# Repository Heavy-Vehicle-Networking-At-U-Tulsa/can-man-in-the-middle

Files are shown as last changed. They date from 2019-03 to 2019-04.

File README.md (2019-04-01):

# CAN-man-in-the-middle
or better yet, "can-in-the-middle" is system using the TU Truck Cape, a BeagleBone Black, socketCAN and Python3 to inspect and forward CAN network traffic. Particular interest is on J1939 used in heavy trucks. Contributions to this repository are a result of the funded research on heavy vehicle cybersecurity and digital forensics at the University of Tulsa. 

## Setting up the Hardware
The hardware for this project is 100% open. You can purchase every part of the hardware and hand assemble the pieces. The schematic for the Truck Cape or the CAN Man-in-the-middle is shown in the docs folder. There are multiple hardware versions for different form factors and switching functions. All versions use the BeagleBone Black and have 2 CAN channels and 2 J1708 channels. For more details, see the docs folder.

## Setting up the Operating System (ARM Linux)
The project is based on the following image:

http://debian.beagleboard.org/images/bone-debian-9.5-iot-armhf-2018-10-07-4gb.img.xz

Follow the instructions at http://beagleboard.org/static/beaglebone/latest/README.htm

Here are a couple modifications to the instructions:

We assume you are using Windows 7 or Windows 10:
To install this system on the BeagleBone eMMC do the following: 
  1. Decompress the image using 7-zip: https://www.7-zip.org/download.html
  2. Write the image file to an SD card using Win32 Imager: https://sourceforge.net/projects/win32diskimager/files/latest/download
  3. Insert the micro SD card into the BeagleBone Black.
  3. Boot the system while holding down the SD boot button. A USB cable can power the BBB for this. 
  4. Log into the system by using Putty to ssh into 192.168.7.2 (with USB). The user is `debian` and the password is `temppwd`
  4. At the command prompt, type  `sudo nano /boot/uEnv.txt`. You may have to enter the password again.
  5. Uncomment the last existing line so it says: `cmdline=init=/opt/scripts/tools/eMMC/init-eMMC-flasher-v3.sh` 
  6. reboot: `sudo shutdown -r now`
  7. The system will reboot and after a minuite or so, the LEDs will flash back and forth then light up solid when finished (10 minutes or so).
  8. Remove the SD card and press the reset button or cycle power.
  9. Login again and finish creating the environment.

user: debian

password: temppwd

It may be helpful to connect to the Internet through Ethernet. Once the Ethernet is plugged in, you can check an IP address through the USB connection using `ifconfig`. Look for the IP address for eth0.

BBone Black Wireless has not been tested yet.

## Accessing the BeagleBone Black

### USB
A mini usb connection has an RNDIS connection for treating the connection like a network. The IP address for the USB connection is 192.168.7.2. However, in Windows 10, the driver for this connection is not install correctly by default. To set up the driver for this, please see this guide.

### Ethernet
The BeagleBone Black is setup by default to have a DHCP client to get an IP address. Therefore, a DHCP server is needed for the device to get an IP address.

### Shell Access
SSH is a prefered method to access the operating system. For Windows users, PuTTy is available.

### File Transfer
WinSCP can handle file transfers over a secure connection from a Windows machine.

### Remote Sublime

To edit files using Sublime in on the Beaglebone, there is a package in Sublime Text 3 called RemoteSubl. https://github.com/randy3k/RemoteSubl

http://blog.keyrus.co.uk/editing_files_on_a_remote_server_using_sublime.html

## Creating the environment.

The baseline is the 4.14.71 Linux Kernel. Verify you have the correct operating system installed. Try the following commands and compare the output.

```
debian@beaglebone:~$ uname -a
Linux beaglebone 4.14.71-ti-r80 #1 SMP PREEMPT Fri Oct 5 23:50:11 UTC 2018 armv7l GNU/Linux
```

```
debian@beaglebone:~$ cat /etc/os-release
PRETTY_NAME="Debian GNU/Linux 9 (stretch)"
NAME="Debian GNU/Linux"
VERSION_ID="9"
VERSION="9 (stretch)"
ID=debian
HOME_URL="https://www.debian.org/"
SUPPORT_URL="https://www.debian.org/support"
BUG_REPORT_URL="https://bugs.debian.org/"
```

```
debian@beaglebone:~$ cat /etc/debian_version
9.5
```

```
debian@beaglebone:~$ cat /etc/dogtag
BeagleBoard.org Debian Image 2018-10-07
```

### Controlling Relays
In the hardware revisions with relays (versions 3 and 4), the configuration of the relay switches enables the MITM to be moved between different networks. 

All relays and LEDs require the 5V0 to be present, which comes from the 12V source. This means if the device is powered with just the USB, the relays won't work.

From the command line:

#### Switch 1
`config-pin P8_39 0`  disconnects J1939 from either side (man-in-the-middle mode).

`config-pin P8_39 1`  connects J1939 (Pins C and D) on the A side to J1939 on the B side (passthrough mode).

#### Switch 2
`config-pin P8_40 0`  connects CAN2 (Pins H and J) on the A side to CAN2 on the B side (passthrough mode).

`config-pin P8_40 1`  disconnects CAN2 from either side (man-in-the-middle mode).

#### Switch 3
`config-pin P8_37 0`  connects the `can1` socket to J1939 (Pins C and D) on the A side.

`config-pin P8_37 1`  connects the `can1` socket to CAN2 (Pins H and J) on the A side.

#### Switch 4
`config-pin P8_42 0` connects J1708 (Pins F and G) on the A side to J1708 (Pins F and G) on the B side.

`config-pin P8_42 1` disconnects J1708 from either side (requires software bridge).

#### Switch 5

`config-pin P8_45 0` connects J1939 (Pins C and D) on the B side to `can0`.

`config-pin P8_45 1` connects CAN2 (Pins H and J) on the B side to `can0`.

#### Switch 6

`config-pin P8_46 0` connects terminating resistors.

`config-pin P8_46 1` connects both beaglebone CAN channels together.

#### LED
`config-pin P8_38 0`  Turns off the board mounted LED.

`config-pin P8_38 1`  Turns on the board mounted LED.

#### Using Python
The `os.system` command enables execution of these commands.

```
debian@beaglebone:~$ python3
Python 3.5.3 (default, Jan 19 2017, 14:11:04)
[GCC 6.3.0 20170118] on linux
Type "help", "copyright", "credits" or "license" for more information.
>>> import os
>>> os.system("config_pin P8_38 1")
```

Or, you can use Adafruit's Python Package:

`sudo apt-get install build-essential python-dev python-pip3 -y`

`sudo pip3 install Adafruit_BBIO`

Example of turning on the LED:
```
debian@beaglebone:~$ python3
Python 3.5.3 (default, Sep 27 2018, 17:25:39)
[GCC 6.3.0 20170516] on linux
Type "help", "copyright", "credits" or "license" for more information.
>>> import Adafruit_BBIO.GPIO as GPIO
>>> GPIO.setup("P8_38",GPIO.OUT)
>>> GPIO.output("P8_38",GPIO.HIGH)
```

### Enabling Relays and CAN on Boot

`sudo nano /boot/uEnv.txt`

Change the following block by uncommenting some lines shown below:

```
###Disable auto loading of virtual capes (emmc/video/wireless/adc)
#disable_uboot_overlay_emmc=1
disable_uboot_overlay_video=1
disable_uboot_overlay_audio=1
#disable_uboot_overlay_wireless=1
disable_uboot_overlay_adc=1
```
Exit and save the file.

Restart `sudo shutdown -r now`

We need to load the GPIO settings into the system to use them.

`sudo nano /etc/rc.local`

Copy the rc.local file contents into this editor. The rc.local file runs on boot. It uses the `config-pin` command to set the pins to the appropriate function (like GPIO or CAN)

`sudo chmod 755 rc.local`

Restart the system. `sudo shutdown -r now`.

`sudo sh rc.local` should produce a series of relay clicks and leave the LED on.

#### Python Program to control relays
A Python module is available to setup common relay configurations or control each relay individually. The examples are as follows:

```
debian@beaglebone:~$ python3
Python 3.5.3 (default, Sep 27 2018, 17:25:39)
[GCC 6.3.0 20170516] on linux
Type "help", "copyright", "credits" or "license" for more information.
>>> from mitmRelays import *
>>> mitm = MITM()
>>> mitm.LED(True)
>>> mitm.switch_1(True)
>>> mitm.switch_1(False)
>>> mitm.switch_2(True)
>>> mitm.switch_2(False)
>>> mitm.switch_3(True)
>>> mitm.switch_3(False)
>>> mitm.switch_4(True)
>>> mitm.switch_4(False)
>>> mitm.switch_5(True)
>>> mitm.switch_5(False)
>>> mitm.switch_6(True)
>>> mitm.switch_6(False)
>>> mitm.passthrough_all_monitor_j1939()
>>> mitm.passthrough_all_monitor_can2()
>>> mitm.mitm_can2()
>>> mitm.mitm_J1939() 
```
#### Autostart can0 and can1
To bring up both CAN interfaces at boot change `/etc/network/interfaces` with the following commands

```
sudo nano /etc/network/interfaces
```

Add these lines at the end of the file.
```
allow-hotplug can0
iface can0 can static
    bitrate 250000
    restart-ms 250
 
allow-hotplug can1
iface can1 can static
    bitrate 250000
    restart-ms 250
```

#### Changing CAN bitrates

```
sudo ip link set can1 down
sudo ip link set can1 type can bitrate 500000 restart-ms 200
sudo ip link set can1 up
```

#### Check CAN Statistics
```
ip -details -statistics link show can1
```

### Exceptions for the Forensic Link Adapter
If running on an FLA, turn the dual CAN switch on and make the change available on boot by adding the following script to `/etc/rc.local`

```
sudo nano /etc/rc.local
```
Enter the following lines:
```
#!/bin/sh -e
echo "70" > /sys/class/gpio/export
echo "out" > /sys/class/gpio/gpio70/direction
echo "1" > /sys/class/gpio/gpio70/value
exit 0
```
Save with Control-X, Y, Enter. Then make it executable:
```
sudo chmod 755 /etc/rc.local
sudo shutdown -r now
```

### Python and CAN
Python 3.5 is installed at this version of Linux. To test this
```
debian@beaglebone:~$ python3
Python 3.5.3 (default, Jan 19 2017, 14:11:04)
[GCC 6.3.0 20170118] on linux
Type "help", "copyright", "credits" or "license" for more information.
>>>
```
Python comes with sockets and socketCAN, which is available by default.
You can also install python-can as an interface:
```
python3 -m pip install python-can
```
Building the dependency of `wrapt` failed to build, but the pip command completed.
 
#### Example Program
The following is a basic Python3 program to forward can messages from one socket to another.
```
#!/bin/env python
import socket
import struct

canformat = '<IB3x8s'

class CanBridge():
    def __init__(self, interface_from, interface_to):
        self.interface_from = interface_from
        self.interface_to = interface_to
        self.canSocket_to = socket.socket(socket.PF_CAN, socket.SOCK_RAW, socket.CAN_RAW)
        self.canSocket_from = socket.socket(socket.PF_CAN, socket.SOCK_RAW, socket.CAN_RAW)
        try: 
            self.canSocket_to.bind((self.interface_to,))
            self.canSocket_from.bind((self.interface_from,))
        except OSError: 
            print("Could not bind to interfaces")
        #put the sockets in blocking mode.
        self.canSocket_to.settimeout(None)
        self.canSocket_from.settimeout(None)

    def run(self):
        while True:
            raw_bytes = self.canSocket_from.recv(512)
            try:
                self.canSocket_to.send(raw_bytes)
            except OSError: #Buffer overflow usually from lack of connection.
                pass

            rawID,DLC,candata = struct.unpack(canformat,raw_bytes)
            canID = rawID & 0x1FFFFFFF
            candata_string = " ".join(["{:02X}".format(b) for b in candata])
            print("{:08X} {}".format(canID, candata_string))

if __name__ == '__main__':
    bridge = CanBridge('can1','can0')
    bridge.run()
```
Another simple program using the `python-can` library:
```
#!/bin/env python3
import can

bus = can.interface.Bus(bustype='socketcan', channel='can1', bitrate=250000)
try:
    while True:
        message = bus.recv()
        candata_string = " ".join(["{:02X}".format(b) for b in message.data])
        print("{:08X} {}".format(message.arbitration_id, candata_string))
except KeyboardInterrupt:
    bus.shutdown()
    print("Finished.")
```
There is a noticeable delay when starting this program. The output is as follows when connected to a brake controller and a Smart Sensor Simulator 2:
```
18FEBF0B 00 00 7D 7D 7D 7D FF FF
0CFE6E0B 00 00 00 00 00 00 00 00
0CFE6E0B 00 00 00 00 00 00 00 00
0CFE6E0B 00 00 00 00 00 00 00 00
18FEF10B FF 00 00 FF FF FF FF FF
0CFE6E0B 00 00 00 00 00 00 00 00
18F00131 00 00 00 00 00 00 00 00
18F0010B 00 00 00 00 00 00 00 00
18FEF117 00 00 00 00 00 00 00 00
18FEF128 00 00 00 00 00 00 00 00
18FEF121 00 00 00 00 00 00 00 00
18FEF131 00 00 00 00 00 00 00 00
18E00017 00 00 00 00 00 00 00 00
^CFinished.
```

## Testing with an SSS2
Plug in the CAN-in-the-middle to the Smart Sensor Simulator 2 and turn on the keyswitch of the SSS2 (press the knob for 2 seconds).
Log into the BeagleBone and run `candump any` to see a stream of CAN traffic. Both green and red leds on the SSS2should be on.

Try `cangen can0` to see the green led ficker. Try `cangen can1` to see the red led flicker. 

### Using CAN Utils as a bridge

`candump -s 2 -B can0 can1&`

`candump -s 2 -B can1 can0&`

will bridge the two networks.

To make this into a service that runs on boot add these two lines to the `/etc/rc.local` file. 

can-utils is installed in `/usr/bin`
```
$ which candump
/usr/bin/candump
```

### Remote Access
Interfacing with CAN over Ethernet has been done in this project.

https://github.com/Heavy-Vehicle-Networking-At-U-Tulsa/TruckCapeProjects/tree/master/SocketCAN

In this project, CAN data is efficiently transferred over TCP for remote interaction.

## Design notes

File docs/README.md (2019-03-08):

# Hardware revisions that work with the MITM
There are multiple hardware versions that can work with the man-in-the-middle programming. There are two main differences in the hardware that are delineated by where the network switching takes place. The MITM can be either on the normal CAN bus as a single node or it can be physically separating two different busses. If the MITM is inserted into an existing bus and separates it into two different CAN busses, then the terminating resistors need to be installed. In the first iteration of this, an external hardware box was built to make the connections and add terminating resitors. In subsequent builds, this switching was done using relays. 

## Truck Cape with an External Man-in-the-Middle
The circuit board for a small network splitter is in the folder labeled Hardware Version 2. This includes Altium designer files and a schematic. The connection to this board is done with a DSUB-15 connector. The network switching is done by reqiring the outside connectors.

## MITM v3
This board was designed to be a utility for inserting a man-in-the-middle in any heavy vehicle network using a deutsch 9-pin carrying 2 CAN channels and a J1708 channel. The relays on this board are setup to insert the CAN channels on the BeagleBone Black in either of the can channels from the vehicle. The details for the hardware and the errata are contained in the Hardware Version 3 directory.

## MITM v4
The directory labeled Hardware Version 4 includes the source documents for the MITM v4 that includes the fixes needed to make Rev3 MITM functional. This hardware has not been built yet (as of 4 March 2019).

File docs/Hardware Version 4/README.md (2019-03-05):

# CAN MITM Hardware Rev 4

The Schematics are available as a pdf. Revision 4 is a hardware version that fixes the errata of the version 3 board. 

You can buy version 4 boards from [OSH Park](https://oshpark.com/shared_projects/IROrdsvO)

The bill of materials is the same for revision 3.

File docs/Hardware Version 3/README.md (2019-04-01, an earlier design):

# Truck Cape Revision 3 MITM Hardware
This readme describes how to build the Man-in-the-middle Revison 3.

The circuit was insipired by the Truck Cape, which was inspired by the Truck Duck, which was inspired by the Forensic Link Adapter. 

The Schematic is in PDF format.

## Errata
In hardware version 3 MITM, there are a few issues to address:
  1. The relays need to be mounted on the bottom of the board to get the correct polarity of voltage across the coil. This has been fixed in MITM rev 4.
  2. The pin going to P8_41 needs to be clipped off the header or removed. This is for switch 3. A jumper wire needs to be routed from pin3 of U2 to P8_37, which is GPIO78.
  3. The LED1 net was not connected. Add a jumper wire from P8_38 (GPIO79) to U2 Pin 7. 
  4. Relay K2 crosses CAN2 H and L. This is fixed by scratching out the traces and connecting jumper wires to the correct polarity on CAN2HB and CAN2LB.

### Boot Pin Changes
Clip pin 41 to ensure the BeagleBone Black will boot. A mechanical pencil shows where pin 41 on P8 is that need to be removed. This pin is routed to P8_37 to be used.

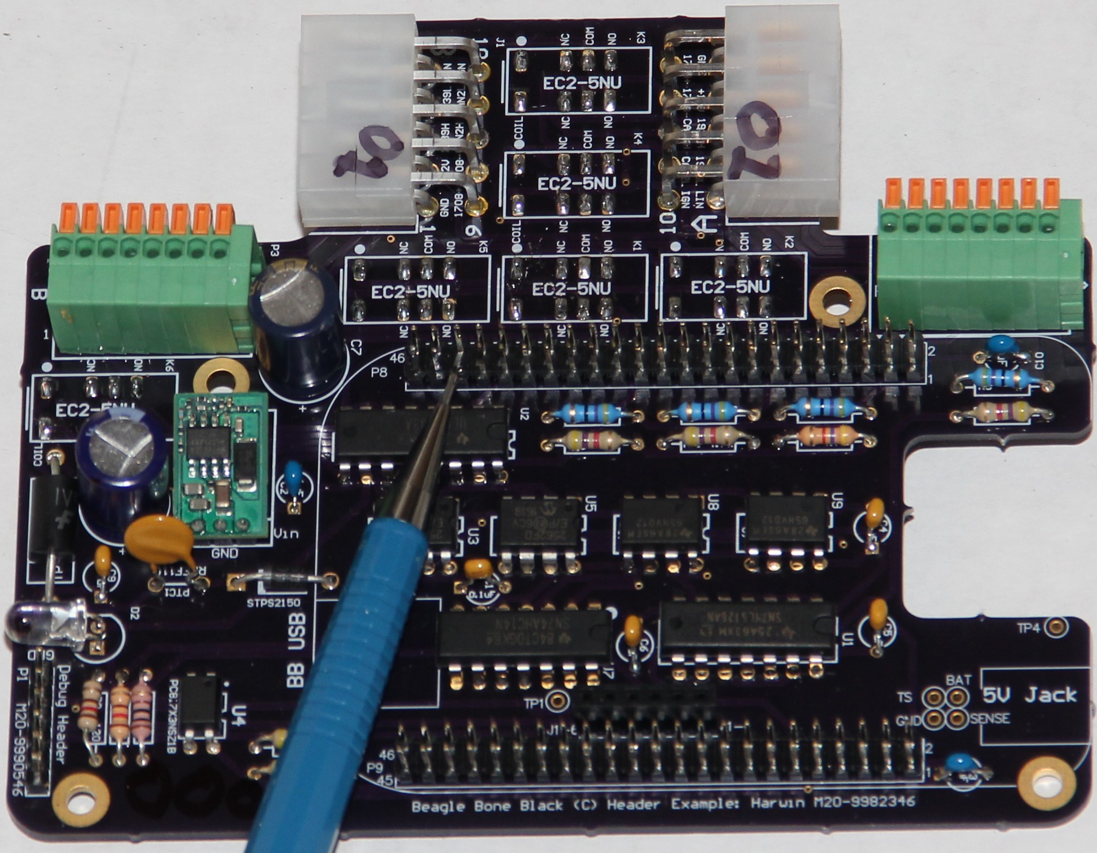
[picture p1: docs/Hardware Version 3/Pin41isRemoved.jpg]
Clip Pin


### Crossed CAN2 Wires
The traces near the relay need to be cut and rerouted. Use a razor knife to cut a small chunk from the two traces for CAN2 between relays K1 and K2 on the top side of the board. See photos.

Cut CAN2H-B

Cut CAN2L-B

Connect the CAN2H wire to the post on K2 that says NC closest to the Beagle Bone and route this to CAN2H on the B side.

Connect the CAN2L wire to the post on K2 directly across from the NC connection and is closest to the Molex Connector and route this to CAN2L on the B side. 

The wires may wrap around the board as seen in the photos.

Topside mount

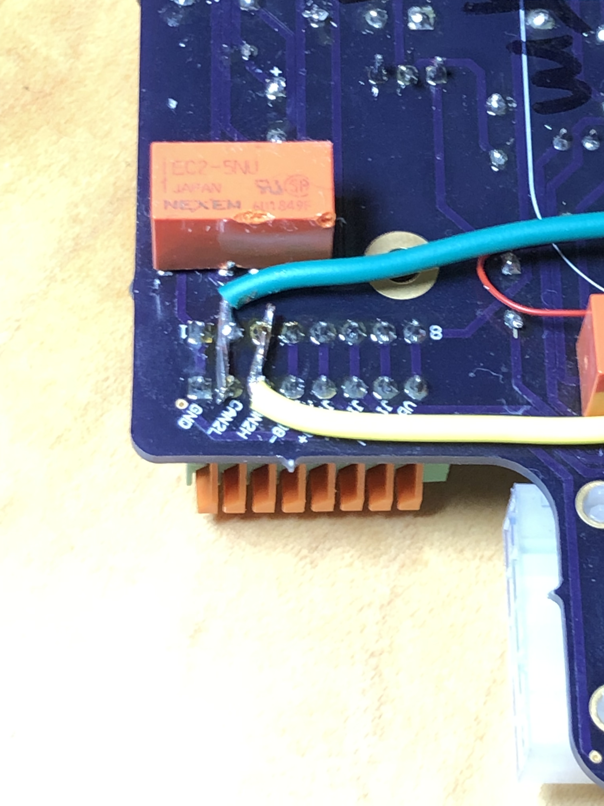
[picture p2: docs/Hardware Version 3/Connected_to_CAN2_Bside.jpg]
Bottomside mount


Bottom View

### Net Labels
The net for Switch4 (P8_42) is connected to Coil4, but that powers Relay K3. This is for the J1708 circuit.

The net for Switch3 (P8_37) is connected to Coil3 powers Relay K4 (after clipping Pin 41). This is for the DCAN1 circuit. This should default to the on position so DCAN1 does not affect CAN2.

## Build process
All parts are through hole parts. A bill of materials in table format is included to help acquire the parts. The silkscreen on the PCB is labeled by part number or value, so hand assembly should be pretty straight forward. Have a look at some of the photos to see the final product.

### Top View

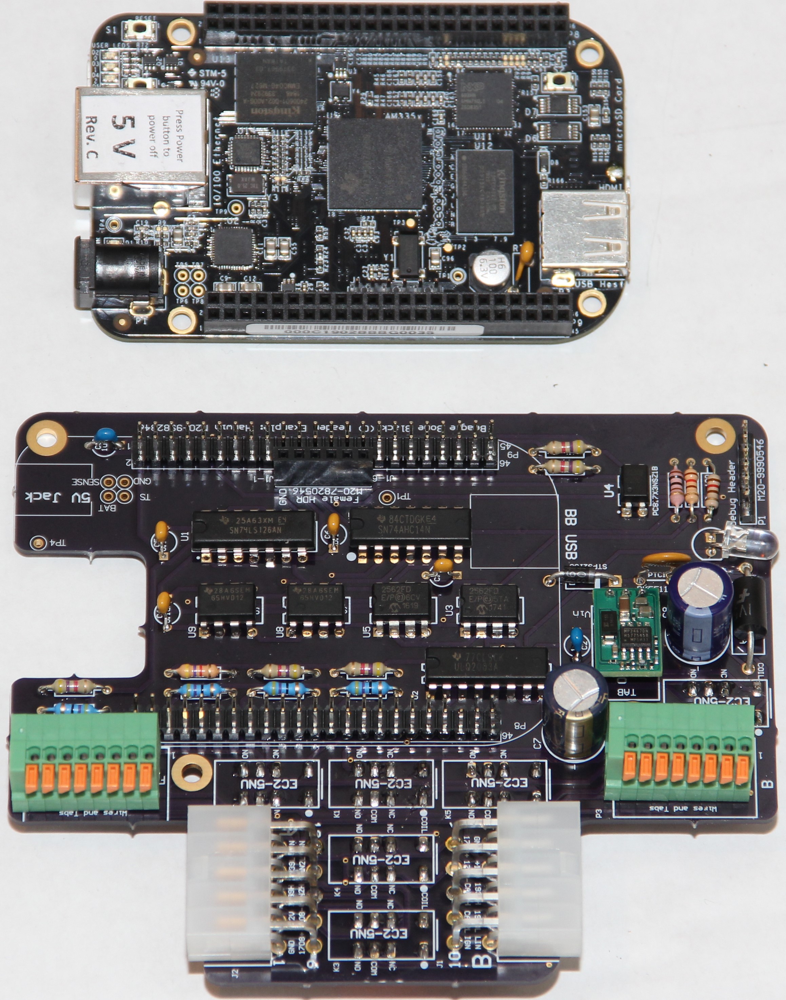
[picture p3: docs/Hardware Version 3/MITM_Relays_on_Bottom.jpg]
Top View


### Bottom View
The bottom of board shows the relays and the wire tracing.

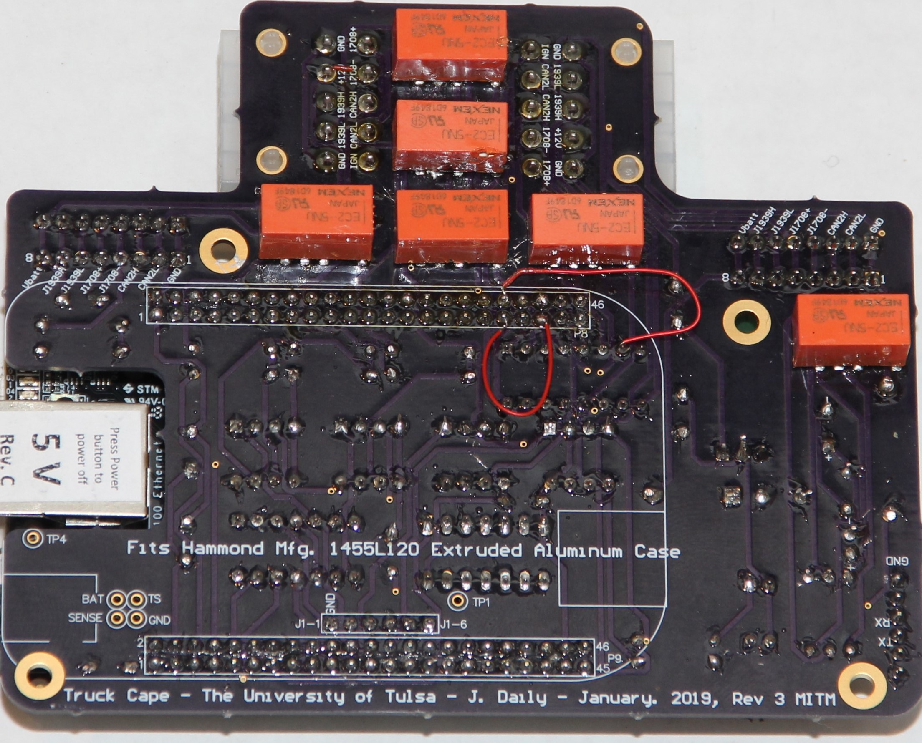
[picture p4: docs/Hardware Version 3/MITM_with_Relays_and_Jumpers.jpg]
Bottom View


The printed circuit board was purchased from OSH Park. Since there are issues with the circuit, this is not a shared board. See the Hardware Revision 4 directory to get a new boards made. 

### End Panels
The end connectors are cut with an epilog laser cutter. Each end is cut one side is for the BeagleBone Black and the other side is for the LED and cables.

The pdf used for the laser cutter has a hole for the cord grip and the BeagleBone Black openings. 

BeagleBone End

LED End

The settings on the 40 watt Epilog laser cutter was 17% speed with 100% power and max frequency. The plastic end panels were placed in the upper left corner of the laser cutter facing down. 

## PCBs
If you want your own boards made, you can send a board house these [gerber files](TruckCapeHammondRev3MITM.zip) as a zip file. However, these boards have the issues corrected by the errata built in; it is advised to use a Rev 4 MITM board.

## Top Level Bill of Materials

| Description | Quantity | Manufacturer | Mfg. Part Number | Supplier Link |
|---|---|---|---|---|
| Anodized extruded aluminum enclosure with plastic end panels | 1 | Hammond Mfg. | 1455N1202BK | [Digi-key](https://www.digikey.com/product-detail/en/hammond-manufacturing/1455N1202BK/HM1501-ND/460176) |
| BeagleBone Black Rev C | 1 | GHI Electropnics LLC | BBB01-SC-505-ND | [Digi-key](https://www.digikey.com/product-detail/en/ghi-electronics-llc/BBB01-SC-505/BBB01-SC-505-ND/6210999) |
| Cord Grip or Cable Gland | 2 | Bud Industries | IPG-22211 | [Digi-key](https://www.digikey.com/product-detail/en/bud-industries/IPG-22211/377-2185-ND/5291487) |
| Cable with Dual Headed 9-pin adapters | 2 | Car-link Auto | KL068-04 | N/A |
| Molex 10 pin Mini-fit Jr connectors | 2 | Molex | 39-01-2100 | [Digi-key](https://www.digikey.com/product-detail/en/molex/39-01-2100/WM3704-ND/61385) |
| Circuit Card Assembly | 1 | DG Technologies | DG-MITM | https://www.dgtech.com |

### Circuit Card Assembly
If you want to build one of these for yourself, the printed circuit board is available as an [order from OSH Park](https://oshpark.com/shared_projects/IROrdsvO).

The bill of materials for the circuit card assembly is as follows:

| Comment |  Designator  | Quantity | Manufacturer | Part Number | Supplier | Supplier Part Number |
| --- | --- | --- | --- | ---  | --- | --- |
| BeagleBoneBlack  | BeagleBoneBlack1 |  2 | Sullins Connector Solutions | PREC023DAAN-RC | Digi-Key | S2012EC-23-ND |
| 0.1uF  | C1, C4, C5, C6, C9  | 5 | Vishay BC Components | K104K20X7RH53H5 | Digi-Key | BC5139-ND |
| 1uF  | C2, C3, C10 | 3 | Murata Electronics North America | RDER72A105K2M1H03A | Digi-Key | 490-9198-1-ND |
| 220uF | C7, C8 |  2 | EPCOS (TDK) | B41858C6227M000 | Digi-Key | 495-6000-ND |
| STPS2150  | D1 | 1 | STMicroelectronics | STPS2150 | Digi-Key | 497-3213-1-ND |
| LED | D2  | 1 | Lite-On Inc. | LTL-4233 | Digi-Key | 160-1130-ND |
| Molex 39-30-1100 | J1, J2  | 2 | Molex | 39-30-1100 | Digi-Key | WM1355-ND |
| EC2-5NU Relay-DPDT  | K1, K2, K3, K4, K5, K6  | 6 | KEMET | EC2-5NU | Digi-Key | 399-11052-5-ND |
| J1-1 to J1-6 |  P1 | 1 | Sullins Connector Solutions | PPPC061LFBN-RC | Digi-Key | S7039-ND |
| Header 8H |  P2, P3 |  2 | Phoenix Contact | 1789472 | Digi-Key | 277-14044-ND |
| RKEF110 | PTC1 | 1 | Littelfuse Inc. | RKEF110 | Digi-Key | RKEF110HF-ND |
| 4.7k | R1, R2, R3, R6, R7, R11, R13  | 7 | Yageo | CFR-25JB-52-4K7 | Digi-Key | 4.7KQBK-ND |
| 47 | R4, R5, R9, R10  | 4 | Yageo | CFR-25JB-52-47R | Digi-Key | 47QBK-ND |
| 120  | R8, R12  | 2 | Yageo | MFP-25BRD52-120R | Digi-Key | 120ADCT-ND |
| SN74LS126AN  | U1  | 1 | Texas Instruments | SN74LS126AN | Digi-Key | 296-3643-5-ND |
| ULQ2003 Darlington Array | U2  | 1 | Texas Instruments | ULQ2003AN | Digi-Key | 296-22623-5-ND |
| MCP2562 | U3, U5 | 2 | Microchip Technology | MCP2562-E/P | Digi-Key | 296-26344-1-ND |
| LTV-817 | U4  | 1 | Lite-On Inc. | LTV-817 | Digi-Key | 160-1366-5-ND |
| OKI-78SR | U6  | 1 | Murata Power Solutions Inc. | OKI-78SR-5/1.5-W36H-C | Digi-Key | 811-2692-ND |
| SN74AHC14N | U7 | 1 | Texas Instruments | SN74AHC14N | Digi-Key | 296-4550-5-ND |
| SN75HVD12  | U8, U9  | 2 | Texas Instruments | SN75HVD12P | Digi-Key | SN75HVD12P |
| TP1.5KE30CA | Z1  | 1 | Littelfuse Inc. | TP1.5KE30CA | Digi-Key | F7610CT-ND |

This bill of materials should match with the schematic labels and the board outlines.

Installing the LED at the end will ensure that it will mate with the hole in the end panel correctly.

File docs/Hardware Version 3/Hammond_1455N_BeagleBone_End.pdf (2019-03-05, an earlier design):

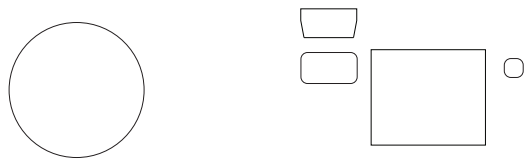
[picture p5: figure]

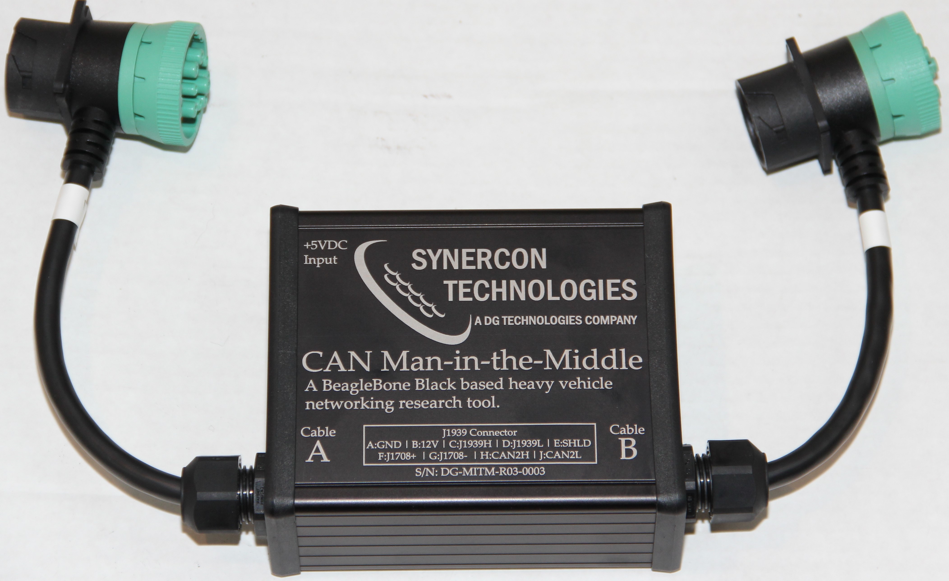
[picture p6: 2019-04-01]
docs/Hardware Version 4/DG Version of CAN Man in the Middle.jpg

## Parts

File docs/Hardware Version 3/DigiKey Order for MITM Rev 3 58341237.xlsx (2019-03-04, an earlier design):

# | Quantity | Part Number | Manufacturer Part Number | Description | Customer Reference | Backorder | Unit Price | Extended Price
1 | 25 | S2012EC-23-ND | PREC023DAAN-RC | CONN HEADER VERT 46POS 2.54MM | P8, P9 | 0 | 0.6576 | 16.44
2 | 100 | BC5139-ND | K104K20X7RH53H5 | CAP CER 0.1UF 100V X7R RADIAL | C1, C4, C5, C6, C9 | 0 | 0.1635 | 16.35
3 | 40 | 490-9198-1-ND | RDER72A105K2M1H03A | CAP CER 1UF 100V X7R RADIAL | C2, C3, C10 | 0 | 0.616 | 24.64
4 | 30 | 495-6000-ND | B41858C6227M000 | CAP ALUM 220UF 20% 50V RADIAL | C7, C8 | 0 | 0.463 | 13.89
5 | 10 | 497-3213-1-ND | STPS2150 | DIODE SCHOTTKY 150V 2A DO15 | D1 | 0 | 0.43 | 4.30
6 | 20 | WM1355-ND | 0039301100 | CONN HEADER R/A 10POS 4.2MM | J1, J2 | 0 | 1.243 | 24.86
7 | 10 | S7039-ND | PPPC061LFBN-RC | CONN HDR 6POS 0.1 GOLD PCB |  | 0 | 0.5 | 5.00
8 | 25 | 732-5319-ND | 61300611121 | CONN HEADER VERT 6POS 2.54MM |  | 0 | 0.232 | 5.80
9 | 65 | 399-11052-5-ND | EC2-5NU | RELAY GEN PURPOSE DPDT 2A 5VDC | K1, K2, K3, K4, K5, K6 | 0 | 1.292 | 83.98
10 | 10 | RKEF110HF-ND | RKEF110 | PTC RESET FUSE 60V 1.1A RADIAL | PTC1 | 0 | 0.519 | 5.19
11 | 100 | 4.7KQBK-ND | CFR-25JB-52-4K7 | RES 4.7K OHM 1/4W 5% AXIAL | R1, R2, R3, R6, R7, R11, R13 | 0 | 0.0258 | 2.58
12 | 50 | 47QBK-ND | CFR-25JB-52-47R | RES 47 OHM 1/4W 5% AXIAL | R4, R5, R9, R10 | 0 | 0.036 | 1.80
13 | 10 | 296-3643-5-ND | SN74LS126AN | IC BUF NON-INVERT 5.25V 14DIP | U1 | 0 | 0.726 | 7.26
14 | 25 | MCP2562-E/P-ND | MCP2562-E/P | IC TXRX CAN 8DIP | U3, U5 | 0 | 0.8036 | 20.09
15 | 10 | 160-1366-5-ND | LTV-817 | OPTOISOLATR 5KV TRANSISTOR 4-DIP | U4 | 0 | 0.294 | 2.94
16 | 10 | 811-2692-ND | OKI-78SR-5/1.5-W36H-C | DC DC CONVERTER 5V 8W | U6 | 0 | 4.474 | 44.74
17 | 10 | 296-4550-5-ND | SN74AHC14N | IC INVERTER SCHMITT 6CH 14DIP | U7 | 0 | 0.476 | 4.76
18 | 20 | 296-14047-5-ND | SN75HVD12P | IC TRANSCEIVER RS485 3.3V 8-DIP | U8, U9 | 0 | 3.675 | 73.50
19 | 10 | F7610CT-ND | TP1.5KE30CA | TVS DIODE 25.6V 41.4V DO201 | Z1 | 0 | 0.757 | 7.57
20 | 10 | 160-1130-ND | LTL-4233 | LED GREEN DIFFUSED T-1 3/4 T/H | D2 | 0 | 0.262 | 2.62
21 | 20 | 277-14044-ND | 1789472 | TERM BLK 8POS TOP ENT 2.54MM PCB | P2, P3 | 0 | 9.325 | 186.50
22 | 10 | 296-22623-5-ND | ULQ2003AN | IC PWR RELAY 7NPN 1:1 16DIP | U2 | 0 | 0.752 | 7.52
23 | 25 | 120ADCT-ND | MFP-25BRD52-120R | RES 120 OHM 1/4W 0.1% AXIAL | R8, R12 | 0 | 0.4068 | 10.17

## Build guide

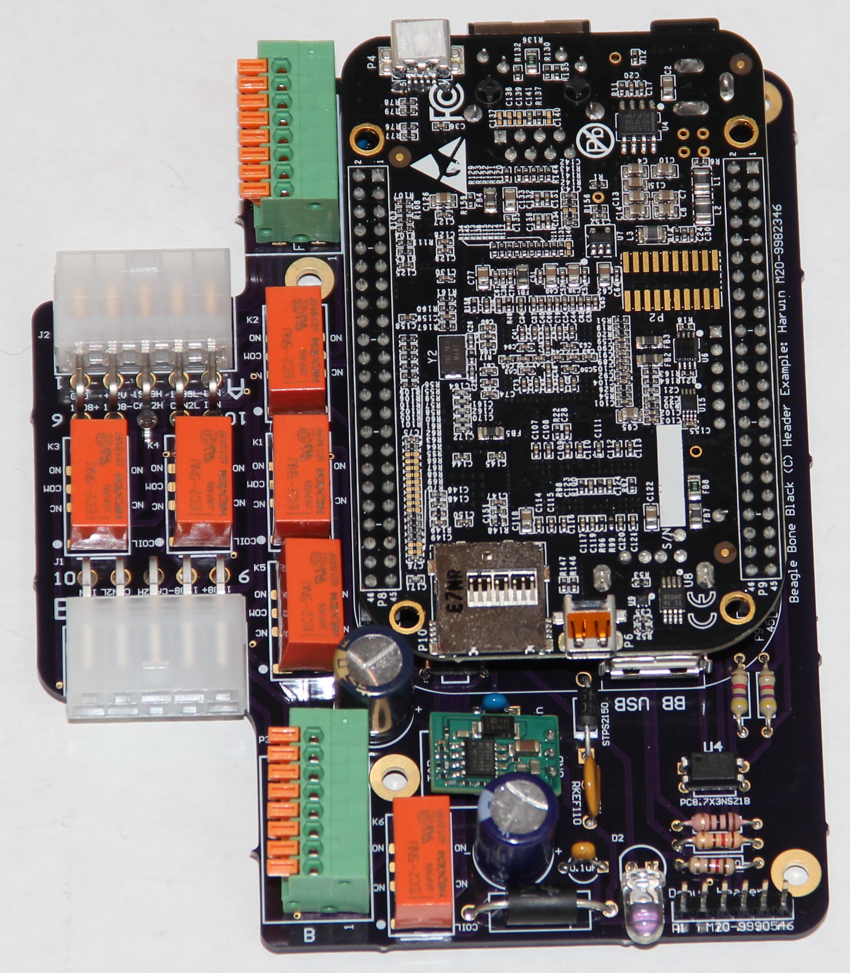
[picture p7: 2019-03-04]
docs/Hardware Version 4/Assembled CAN MITM board top.jpg

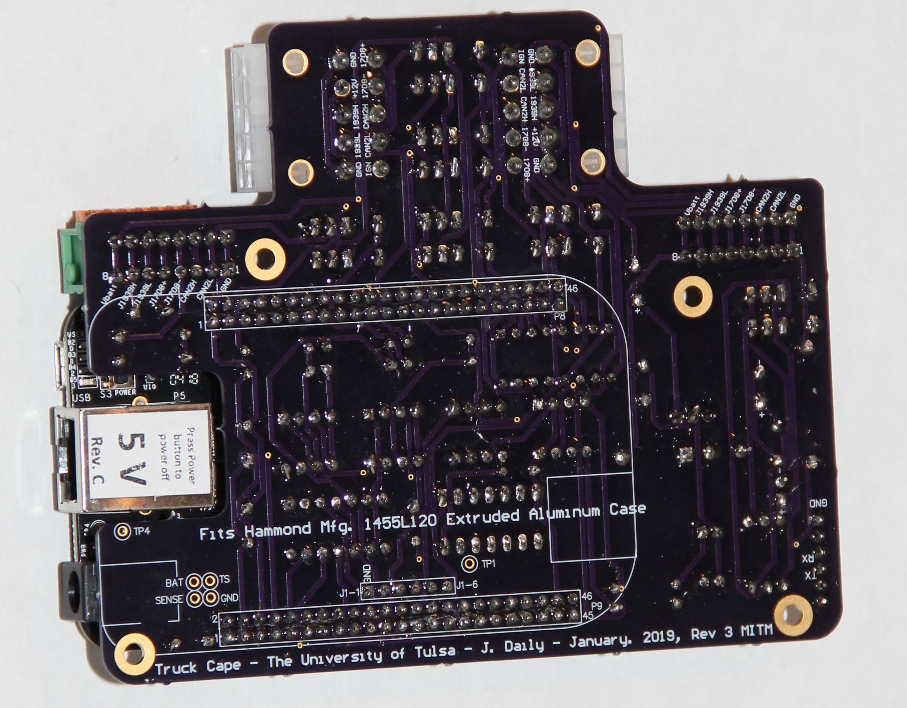
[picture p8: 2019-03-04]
docs/Hardware Version 4/Assembled CAN MITM board bottom.jpg

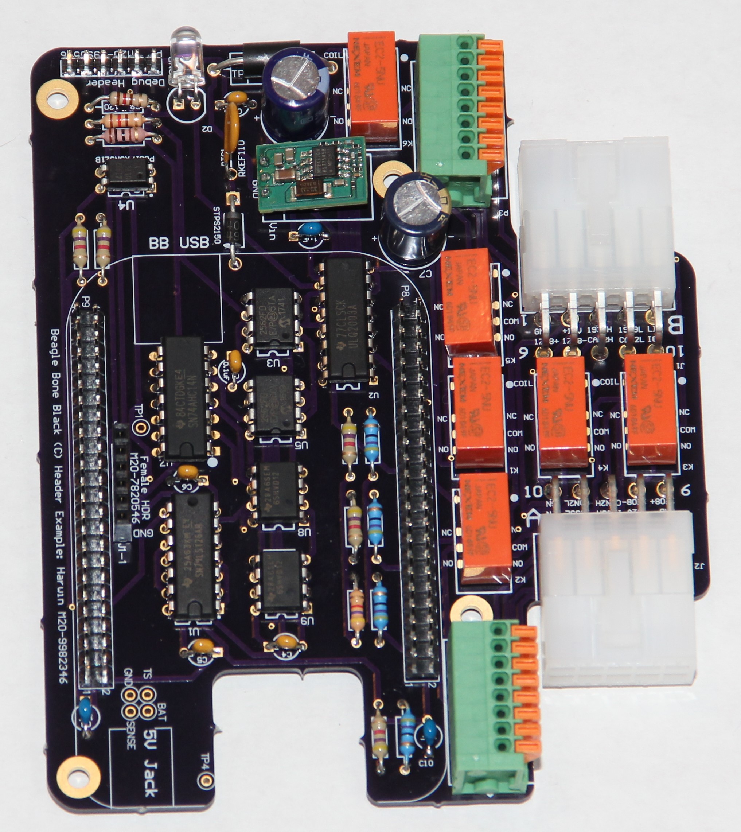
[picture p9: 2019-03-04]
docs/Hardware Version 4/Assembled CAN MITM board top no BBB.jpg

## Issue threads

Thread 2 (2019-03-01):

How to resolve the following error:AttributeError: 'CanBridge' object has no attribute 'run'

Prriyamvradha, 2019-03-01:
I am using two CANtact toolkits(CAN bus) connected by means of DB9 female to DB9 female cable. I want to send CAN a message from one toolkit and the message has to be received in the other toolkit. I used the following code you have mentioned in python3.I get the following error
AttributeError: 'CanBridge' object has no attribute 'run'.How can I resolve it and can this program be used for my case?

```
!/bin/env python
import socket
import struct

canformat = '<IB3x8s'

class CanBridge():
    def __init__(self, interface_from, interface_to):
        self.interface_from = interface_from
        self.interface_to = interface_to
        self.canSocket_to = socket.socket(socket.PF_CAN, socket.SOCK_RAW, socket.CAN_RAW)
        self.canSocket_from = socket.socket(socket.PF_CAN, socket.SOCK_RAW, socket.CAN_RAW)
        try:
            self.canSocket_to.bind((self.interface_to,))
            self.canSocket_from.bind((self.interface_from,))
        except OSError:
            print("Could not bind to interfaces")
        #put the sockets in blocking mode.
        self.canSocket_to.settimeout(None)
        self.canSocket_from.settimeout(None)

    def run(self):
        while True:
            raw_bytes = self.canSocket_from.recv(512)
            try:
                self.canSocket_to.send(raw_bytes)
            except OSError: #Buffer overflow usually from lack of connection.
                pass

            rawID,DLC,candata = struct.unpack(canformat,raw_bytes)
            canID = rawID & 0x1FFFFFFF
            candata_string = " ".join(["{:02X}".format(b) for b in candata])
            print("{:08X} {}".format(canID, candata_string))

if __name__ == '__main__':
    bridge = CanBridge('slcan1','slcan0')
    bridge.run()

```

jeremydaily, 2019-03-01:
This code worked on a BeagleBone Black with a truck cape after I changed  the second to last line to `bridge = CanBridge('can1','can0')`.
The system I tested on was:
```
debian@beaglebone:~$ uname -a
Linux beaglebone 4.14.49-ti-r54 #1 SMP PREEMPT Fri Jun 15 22:14:13 UTC 2018 armv7l GNU/Linux
```
The python version was 3.5. Again, from the terminal:
```
debian@beaglebone:~$ python3
Python 3.5.3 (default, Sep 27 2018, 17:25:39)
[GCC 6.3.0 20170516] on linux
Type "help", "copyright", "credits" or "license" for more information.
>>>
```

Closed 2019-03-01.

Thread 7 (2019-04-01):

Hardware Version 4 schematic still has CAN2-B crossed at K2

traviswparker, 2019-04-01:
The hardware version 4 schematic still has relay K2 connecting CAN2L-A to CAN2H-B and CAN2H-A to CAN2L-B. This is the fault that breaks passthrough on version 3.

jeremydaily, 2019-04-01:
Agreed. There is a hardware version that has been rolled already, so I'll have to post an errata in this directory and look to design a Rev 5 this summer.

Any feature requests?

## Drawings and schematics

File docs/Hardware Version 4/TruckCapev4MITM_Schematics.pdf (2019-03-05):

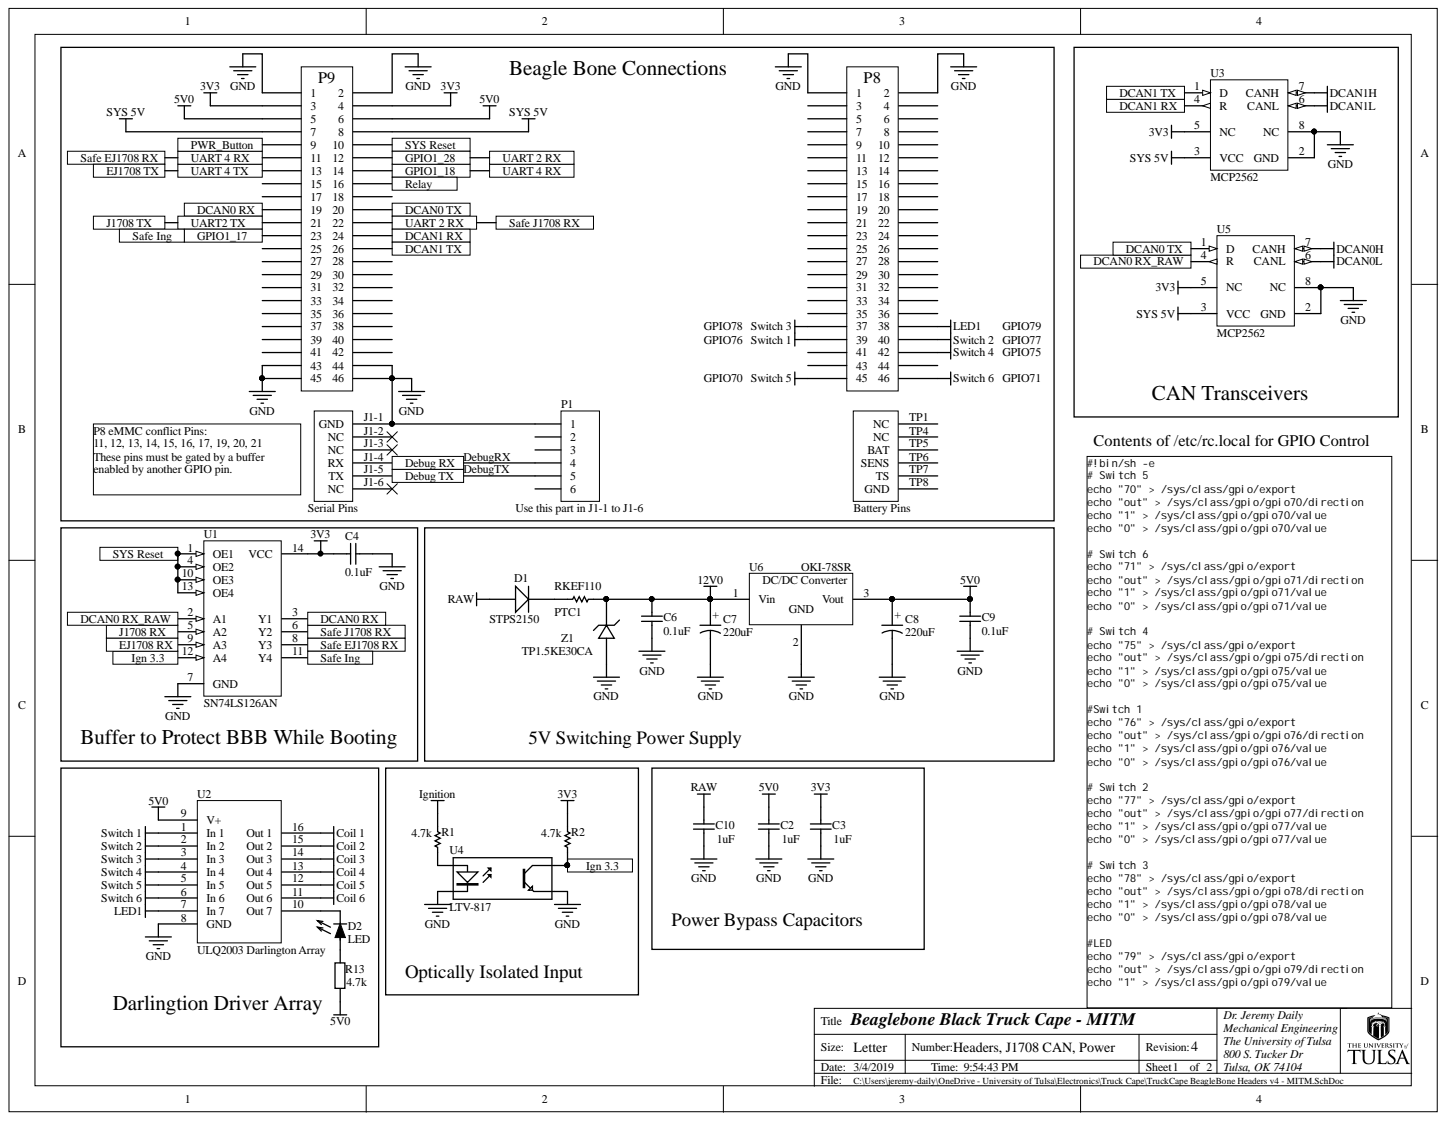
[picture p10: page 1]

P8 eMMC conflict Pins:
These pins must be gated by a buffer
enabled by another GPIO pin.

Contents of /etc/rc.local for GPIO Control

#!bin/sh -e
# Switch 5
echo "70" > /sys/class/gpio/export
echo "out" > /sys/class/gpio/gpio70/direction
echo "1" > /sys/class/gpio/gpio70/value
echo "0" > /sys/class/gpio/gpio70/value

Use this part in J1-1 to J1-6

# Switch 6
echo "71" > /sys/class/gpio/export
echo "out" > /sys/class/gpio/gpio71/direction
echo "1" > /sys/class/gpio/gpio71/value
echo "0" > /sys/class/gpio/gpio71/value

# Switch 4
echo "75" > /sys/class/gpio/export
echo "out" > /sys/class/gpio/gpio75/direction
echo "1" > /sys/class/gpio/gpio75/value
echo "0" > /sys/class/gpio/gpio75/value

EJ1708 RX | Safe EJ1708 RX
Ign 3.3 | Safe Ing

#Switch 1
echo "76" > /sys/class/gpio/export
echo "out" > /sys/class/gpio/gpio76/direction
echo "1" > /sys/class/gpio/gpio76/value
echo "0" > /sys/class/gpio/gpio76/value

Buffer to Protect BBB While Booting

# Switch 2
echo "77" > /sys/class/gpio/export
echo "out" > /sys/class/gpio/gpio77/direction
echo "1" > /sys/class/gpio/gpio77/value
echo "0" > /sys/class/gpio/gpio77/value

# Switch 3
echo "78" > /sys/class/gpio/export
echo "out" > /sys/class/gpio/gpio78/direction
echo "1" > /sys/class/gpio/gpio78/value
echo "0" > /sys/class/gpio/gpio78/value

#LED
echo "79" > /sys/class/gpio/export
echo "out" > /sys/class/gpio/gpio79/direction
echo "1" > /sys/class/gpio/gpio79/value

Beaglebone Black Truck Cape - MITM Title | Dr. Jeremy Daily Mechanical Engineering The University of Tulsa 800 S. Tucker Dr Tulsa, OK 74104

Size: Letter | Headers, J1708 CAN, Power Number: | 4 Revision:

Date: 3/4/2019 | Time: 9:54:43 PM | Sheet 1 of 2

C:\Users\jeremy-daily\OneDrive - University of Tulsa\Electronics\Truck Cape\TruckCape BeagleBone Headers v4 - MITM.SchDoc

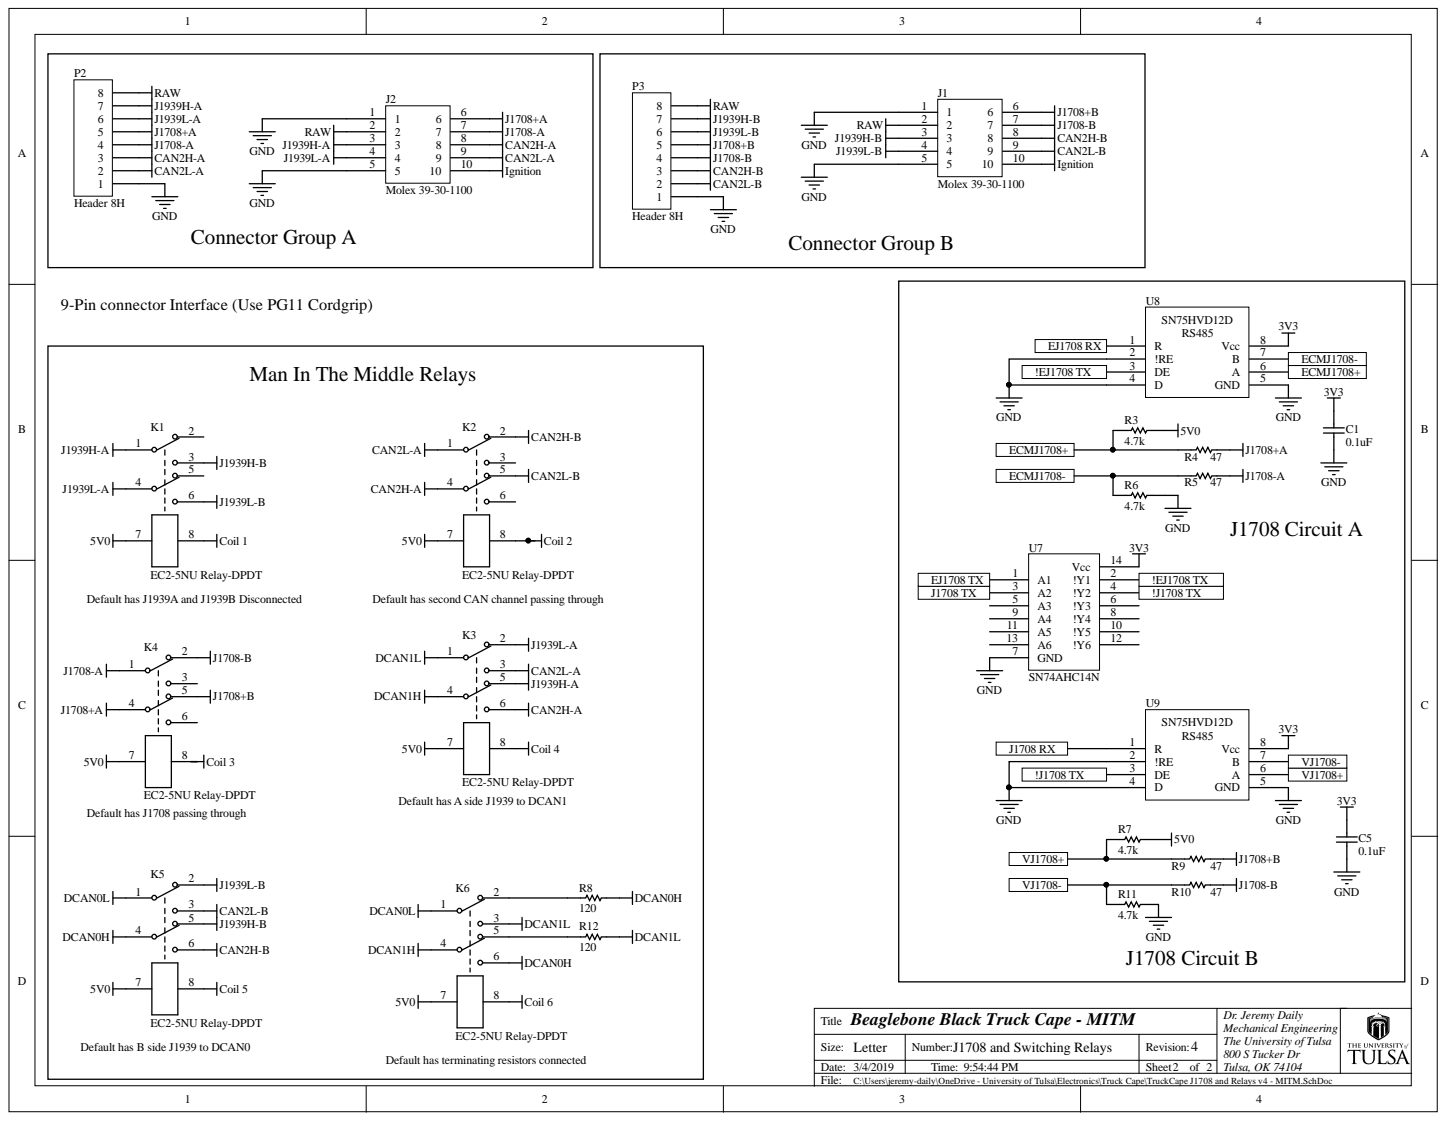
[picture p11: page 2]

9-Pin connector Interface (Use PG11 Cordgrip)

Man In The Middle Relays

!EJ1708 TX | ECMJ1708+

Default has J1939A and J1939B Disconnected

Default has second CAN channel passing through

Default has A side J1939 to DCAN1

Default has J1708 passing through

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

Default has B side J1939 to DCAN0

Size: Letter | J1708 and Switching Relays Number: | 4 Revision:

Default has terminating resistors connected

Date: 3/4/2019 | Time: 9:54:44 PM | Sheet 2 of 2

C:\Users\jeremy-daily\OneDrive - University of Tulsa\Electronics\Truck Cape\TruckCape J1708 and Relays v4 - MITM.SchDoc

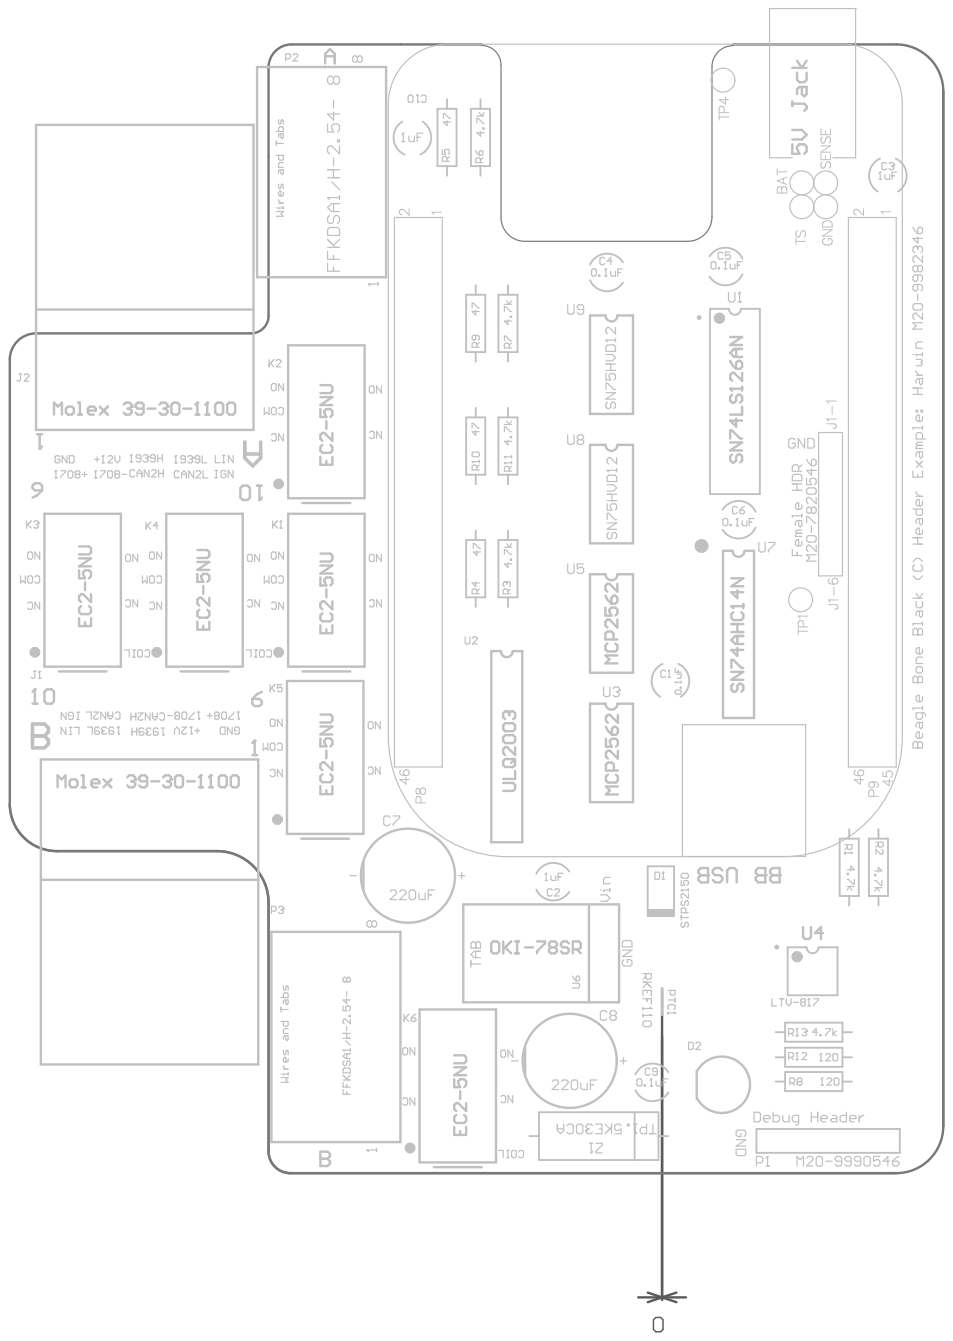
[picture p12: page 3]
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

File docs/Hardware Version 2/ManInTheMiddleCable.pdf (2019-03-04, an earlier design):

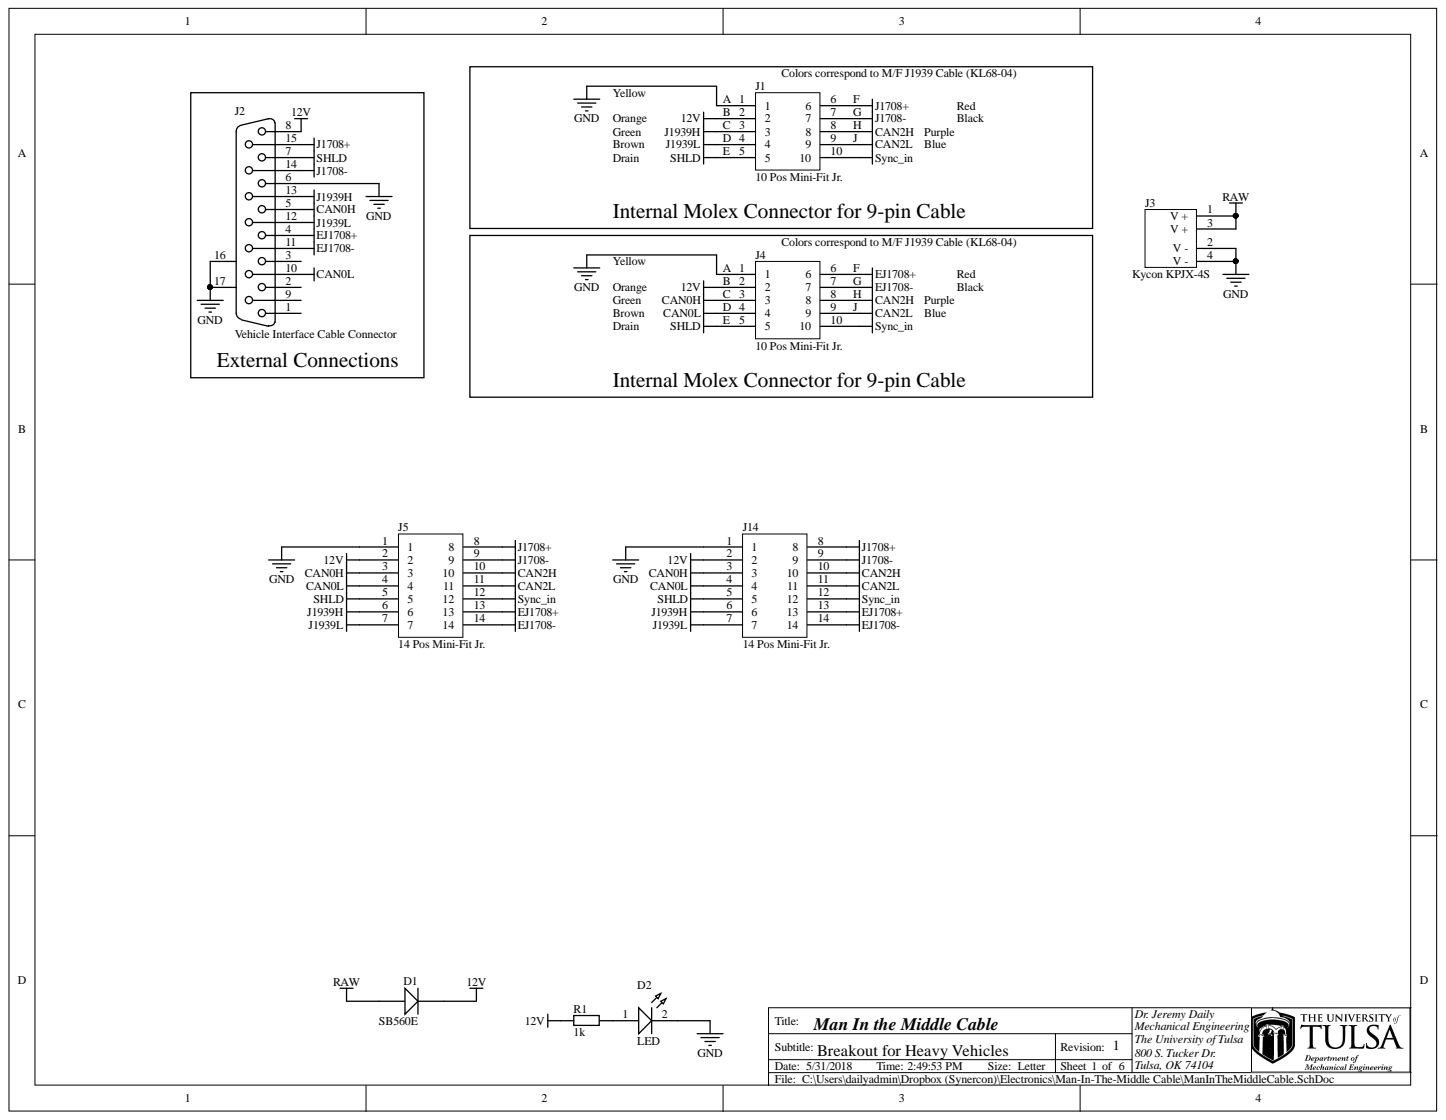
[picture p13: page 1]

Colors correspond to M/F J1939 Cable (KL68-04)

10 Pos Mini-Fit Jr.

Internal Molex Connector for 9-pin Cable

Vehicle Interface Cable Connector
External Connections

14 Pos Mini-Fit Jr.

Title: Man In the Middle Cable | Dr. Jeremy Daily Mechanical Engineering The University of Tulsa 800 S. Tucker Dr. Tulsa, OK 74104

Breakout for Heavy Vehicles Subtitle: | 1 Revision:

Date: 5/31/2018 Time: 2:49:53 PM Size: Letter | Sheet 1 of 6

C:\Users\dailyadmin\Dropbox (Synercon)\Electronics\Man-In-The-Middle Cable\ManInTheMiddleCable.SchDoc

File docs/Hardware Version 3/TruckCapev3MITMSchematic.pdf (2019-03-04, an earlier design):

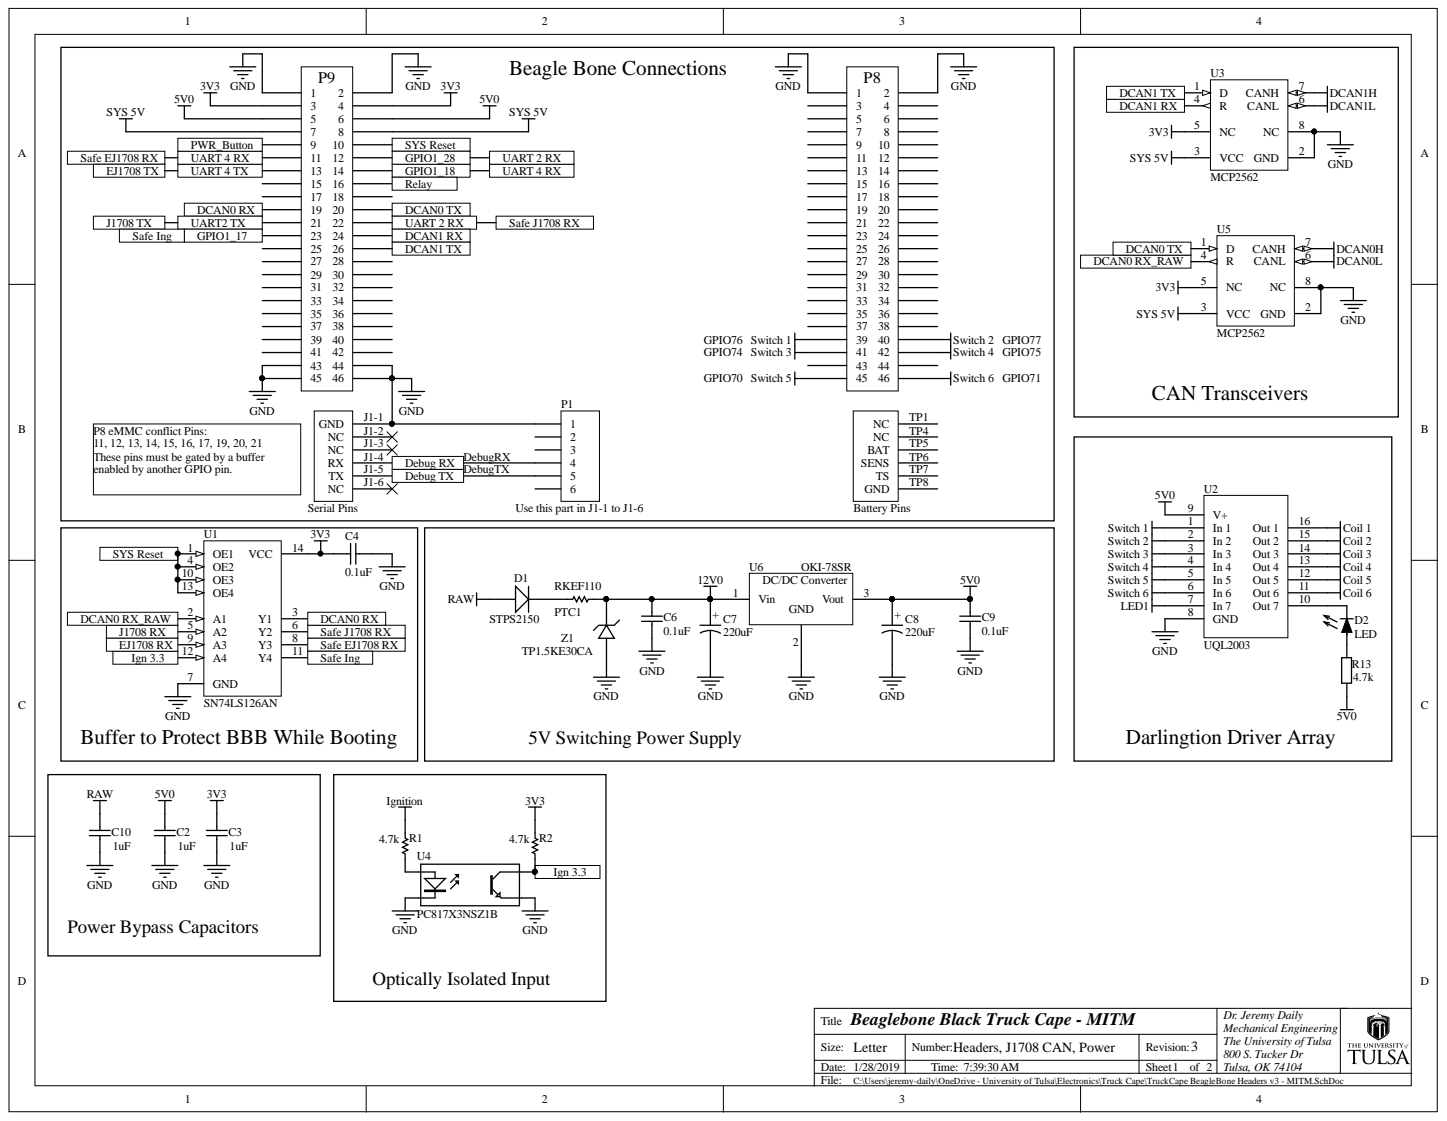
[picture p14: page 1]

P8 eMMC conflict Pins:
These pins must be gated by a buffer
enabled by another GPIO pin.

Use this part in J1-1 to J1-6

Buffer to Protect BBB While Booting

Beaglebone Black Truck Cape - MITM Title | Dr. Jeremy Daily Mechanical Engineering The University of Tulsa 800 S. Tucker Dr Tulsa, OK 74104

Size: Letter | Headers, J1708 CAN, Power Number: | 3 Revision:

Date: 1/28/2019 | Time: 7:39:30 AM | Sheet 1 of 2

C:\Users\jeremy-daily\OneDrive - University of Tulsa\Electronics\Truck Cape\TruckCape BeagleBone Headers v3 - MITM.SchDoc

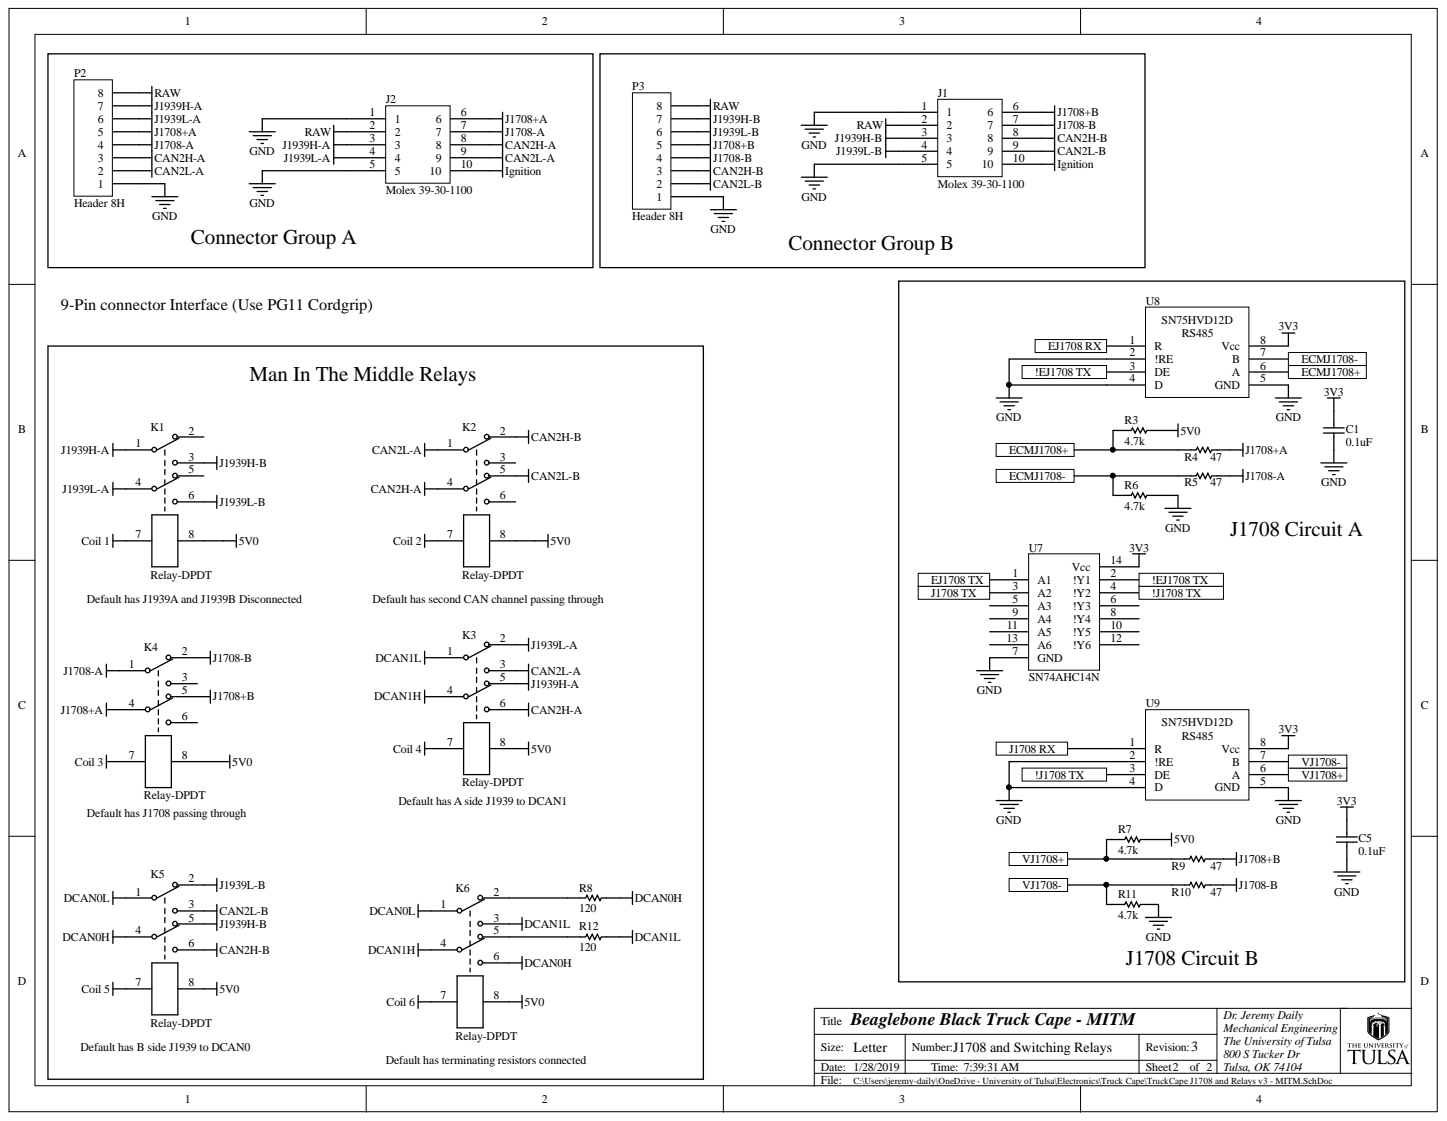
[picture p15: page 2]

9-Pin connector Interface (Use PG11 Cordgrip)

Man In The Middle Relays

!EJ1708 TX | ECMJ1708+

Default has J1939A and J1939B Disconnected

Default has second CAN channel passing through

Default has A side J1939 to DCAN1

Default has J1708 passing through

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

Default has B side J1939 to DCAN0

Size: Letter | J1708 and Switching Relays Number: | 3 Revision:

Default has terminating resistors connected

Date: 1/28/2019 | Time: 7:39:31 AM | Sheet 2 of 2

C:\Users\jeremy-daily\OneDrive - University of Tulsa\Electronics\Truck Cape\TruckCape J1708 and Relays v3 - MITM.SchDoc

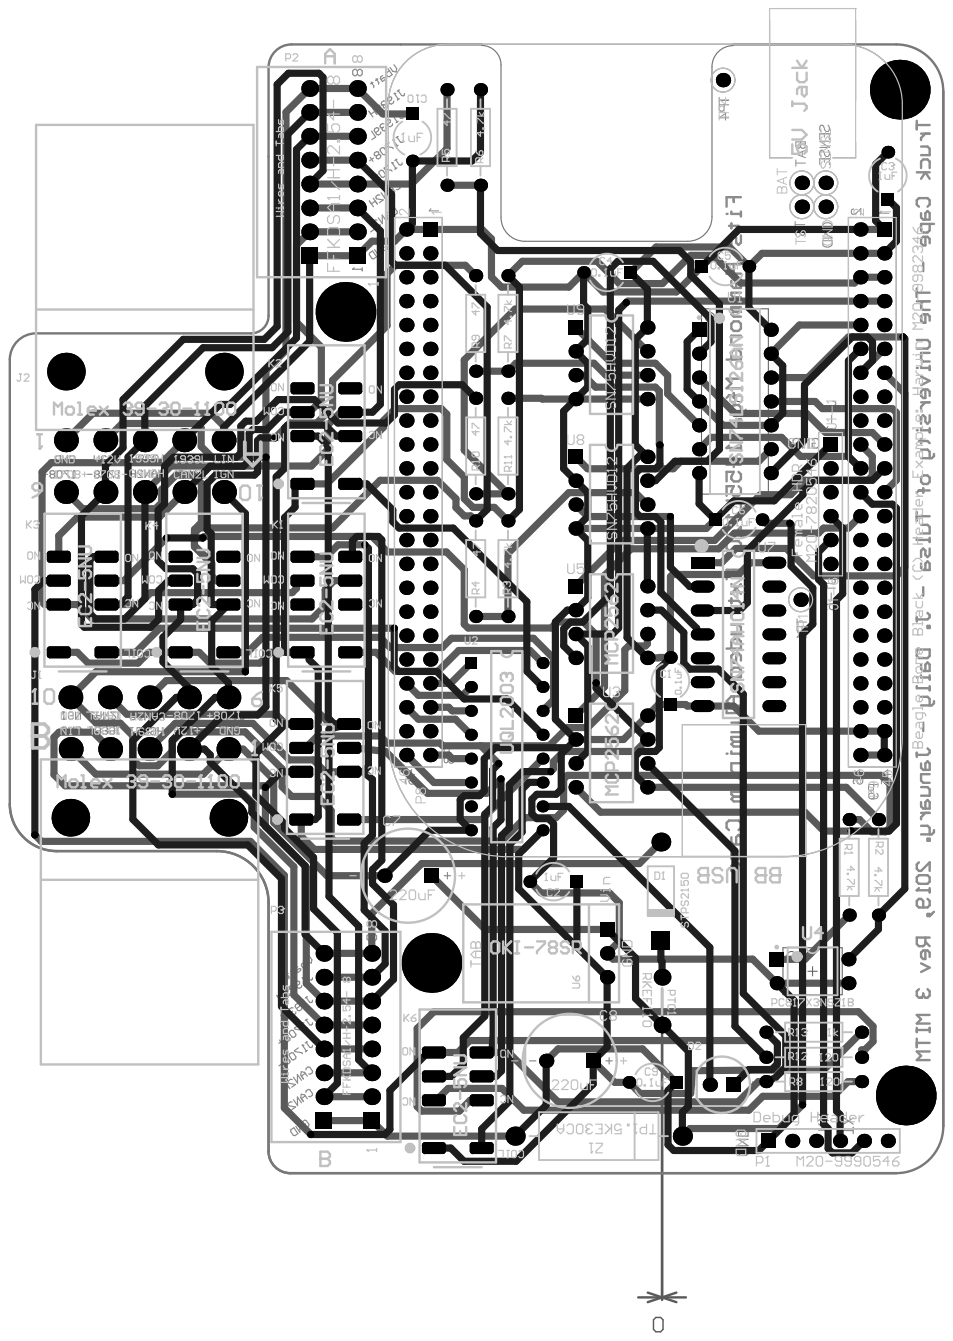
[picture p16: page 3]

Item # | Quantity | Designator | Comment | Footprint | Description | Manufacturer | PartNumber | Supplier 1 | Supplier Part Num#beColr um1 n Name Error:Alte
1 | 1 | BeagleBoneBlack1 | BeagleBoneBlack | Beagleboneblack | 46 Positions Header, Breakaway Connector 0.100" (2.54mm) Through Hole Tin | Sullins Connector Solutions | PREC023DAAN-RC | Digi-Key | S2012EC-23-ND
2 | 5 | C1, C4, C5, C6, C9 | 0.1uF | CAPR5-4X5 | CAP CER 0.1UF 100V X7R RADIAL | Vishay BC Components | K104K20X7RH53H5 | Digi-Key | BC5139-ND
3 | 3 | C2, C3, C10 | 1uF | CAPR5-4X5 | CAP CER 1UF 100V X7R RADIAL | Murata Electronics North America | RDER72A105K2M1H03A | Digi-Key | 490-9198-1-ND
4 | 2 | C7, C8 | 220uF | Elec. Cap 5 x 10mm | 220µF 50V Aluminum Electrolytic Capacitors Radial, Can 175 mOhm @ 10kHz 5000 Hrs @ 105°C | EPCOS (TDK) | B41858C6227M000 | Digi-Key | 495-6000-ND
5 | 1 | D1 | STPS2150 | DO-41 | Diode Schottky 150V 2A Through Hole DO-15 | STMicroelectronics | STPS2150 | Digi-Key | 497-3213-1-ND
6 | 1 | D2 | LED | LED - 5mm Through Hole | Light Emmitting Diode
7 | 2 | J1, J2 | Molex 39-30-1100 | 10 pos Mini-Fit Jr. R/A Header | 10 Positions Header Connector 0.165" (4.20mm) Through Hole, Right Angle Tin | Molex | 39-30-1100 | Digi-Key | WM1355-ND
8 | 6 | K1, K2, K3, K4, K5, K6 | Relay-DPDT | RELAY - EC2 | Dual-Pole Dual-Throw Relay
9 | 1 | P1 | Use this part in J1-1 to J1-6 | HDR1X6 | CONN HEADER FEMALE 6POS .1" GOLD | Sullins Connector Solutions | PPPC061LFBN-RC | Digi-Key | S7039-ND
10 | 2 | P2, P3 | Header 8H | 8 CKT Spring Header | Header, 8-Pin, Right Angle
11 | 1 | PTC1 | RKEF110 | PTC | Polymeric PTC Resettable Fuse 60V 1.1A Ih Through Hole Radial, Disc | Littelfuse Inc. | RKEF110 | Digi-Key | RKEF110HF-ND
12 | 7 | R1, R2, R3, R6, R7, R11, R13 | 4.7k | Axial-0.4 | RES SMD 4.7K OHM 1% 1/10W 0603, Resistor | Yageo, [NoParam] | CFR-25JB-52-4K7, [NoParam] | Digi-Key, [NoParam] | 4.7KQBK-ND, [NoParam]
13 | 4 | R4, R5, R9, R10 | 47 | Axial-0.4 | 47 Ohms ±5% 0.25W, 1/4W Through Hole Resistor Axial Carbon Film | Yageo | CFR-25JB-52-47R | Digi-Key | 47QBK-ND
14 | 2 | R8, R12 | 120 | Axial-0.4 | 47 Ohms ±5% 0.25W, 1/4W Through Hole Resistor Axial Carbon Film | Yageo | CFR-25JB-52-47R | Digi-Key | 47QBK-ND
15 | 1 | U1 | SN74LS126AN | N14A | Quad 3-State Buffer | Texas Instruments | SN74LS126AN | Digi-Key | 296-3643-5-ND
16 | 1 | U2 | UQL2003 | DIP16 | High voltage, high current Darlington arrays each containing seven open collector Darlington pairswith common emitters.
17 | 2 | U3, U5 | MCP2562 | DIP8 | 1/1 Transceiver Half CAN 8-PDIP | Microchip Technology | MCP2562-E/P | Digi-Key | MCP2562-E/P-ND
18 | 1 | U4 | PC817X3NSZ1B | DIP-4 | 4-Pin Phototransistor Optocoupler
19 | 1 | U6 | OKI-78SR | OKI-78SR | 5V DC/DC Converter (7805 replacement) | Murata Power Solutions Inc. | OKI-78SR-5/1.5-W36H-C | Digi-Key | 811-2692-ND
20 | 1 | U7 | SN74AHC14N | DIP14 | Inverter IC 6 Channel Schmitt Trigger 14-PDIP | Texas Instruments | SN74AHC14N | Digi-Key | 296-4550-5-ND
21 | 2 | U8, U9 | SN75HVD12 | DIP8 | IC 3.3V DIFF TXRX 8-SOIC | Texas Instruments | SN75HVD12P | Digi-Key | SN75HVD12P
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

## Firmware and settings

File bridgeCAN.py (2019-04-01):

#!/bin/env python3
import socket
import struct
import os

canformat = '<IB3x8s'

#From https://github.com/torvalds/linux/blob/master/include/uapi/linux/can.h
#special address description flags for the CAN_ID
CAN_EFF_FLAG = 0x80000000 #EFF/SFF is set in the MSB
CAN_RTR_FLAG = 0x40000000 #remote transmission request
CAN_ERR_FLAG = 0x20000000 #error message frame

#valid bits in CAN ID for frame formats
CAN_SFF_MASK = 0x000007FF # /* standard frame format (SFF) */
CAN_EFF_MASK = 0x1FFFFFFF # /* extended frame format (EFF) */
CAN_ERR_MASK = 0x1FFFFFFF # /* omit EFF, RTR, ERR flags */

# 
# Controller Area Network Identifier structure
# 
# bit 0-28 : CAN identifier (11/29 bit)
# bit 29   : error message frame flag (0 = data frame, 1 = error message)
# bit 30   : remote transmission request flag (1 = rtr frame)
# bit 31   : frame format flag (0 = standard 11 bit, 1 = extended 29 bit)
# 

# 
# Controller Area Network Error Message Frame Mask structure
# 
# bit 0-28 : error class mask (see include/linux/can/error.h)
# bit 29-31    : set to zero
# 


# 
# struct can_frame - basic CAN frame structure
# @can_id:  CAN ID of the frame and CAN_*_FLAG flags, see canid_t definition
# @can_dlc: frame payload length in byte (0 .. 8) aka data length code
          # N.B. the DLC field from ISO 11898-1 Chapter 8.4.2.3 has a 1:1
          # mapping of the 'data length code' to the real payload length
# @__pad:   padding
# @__res0:  reserved / padding
# @__res1:  reserved / padding
# @data:    CAN frame payload (up to 8 byte)
# 

# /* particular protocols of the protocol family PF_CAN */
# CAN_RAW     1 /* RAW sockets */
# CAN_BCM     2 /* Broadcast Manager */
# CAN_TP16    3 /* VAG Transport Protocol v1.6 */
# CAN_TP20    4 /* VAG Transport Protocol v2.0 */
# CAN_MCNET   5 /* Bosch MCNet */
# CAN_ISOTP   6 /* ISO 15765-2 Transport Protocol */
# CAN_NPROTO  7


class CanBridge():
    def __init__(self, interface_from, interface_to,bitrate_to=250000,bitrate_from=250000):
        #set CAN bit rates. Must have super user privilages.
        os.system('ip link set {} down'.format(interface_from))
        os.system('ip link set {} type can bitrate {}'.format(interface_from, bitrate_from))
        os.system('ip link set {} up'.format(interface_from))
        os.system('ip link set {} down'.format(interface_to))
        os.system('ip link set {} type can bitrate {}'.format(interface_to, bitrate_to))
        os.system('ip link set {} up'.format(interface_to))

        self.canSocket_to = socket.socket(socket.PF_CAN, 
                                          socket.SOCK_RAW, 
                                          socket.CAN_RAW)
        self.canSocket_from = socket.socket(socket.PF_CAN, 
                                            socket.SOCK_RAW, 
                                            socket.CAN_RAW)
        # Following the RAW Socket Options at
        # https://github.com/torvalds/linux/blob/master/Documentation/networking/can.rst
        # Set receive filters
        # filter passes when <received_can_id> & mask == can_id & mask
        # by setting the mask to zero, all messages pass. 
        can_id = 0
        can_mask = 0
        # Alternatively, to filter out J1939 Cruise Control/Vehicle Speed messages
        # can_id = 0x00FEF100
        # can_mask = 0x00FFFF00 #Just looks at the PGN of 0xFEF1 = 65265
        can_filter = struct.pack('LL',can_id,can_mask)
        
        self.canSocket_to.setsockopt(socket.SOL_CAN_RAW, 
                                     socket.CAN_RAW_FILTER,
                                     can_filter)
        ret_val = self.canSocket_to.getsockopt(socket.SOL_CAN_RAW, socket.CAN_RAW_FILTER)
        print("Socket Option for CAN_RAW_FILTER is set to {}".format(ret_val))
        self.canSocket_from.setsockopt(socket.SOL_CAN_RAW, 
                                     socket.CAN_RAW_FILTER,
                                     can_filter)
        ret_val = self.canSocket_from.getsockopt(socket.SOL_CAN_RAW, socket.CAN_RAW_FILTER)
        print("Socket Option for CAN_RAW_FILTER is set to {}".format(ret_val))
        
        # Set the system to receive every possible error
        can_error_filter = struct.pack('L',CAN_ERR_MASK)
        # Alternatively, we can set specific errors where the errors are enumerated
        # in the defines of /linux/can/error.h
        # can_error_filter = CAN_ERR_TX_TIMEOUT | CAN_ERR_BUSOFF
        self.canSocket_to.setsockopt(socket.SOL_CAN_RAW, 
                                     socket.CAN_RAW_ERR_FILTER,
                                     can_error_filter)
        ret_val = self.canSocket_to.getsockopt(socket.SOL_CAN_RAW, socket.CAN_RAW_ERR_FILTER)
        print("Socket Option for CAN_RAW_ERR_FILTER is set to {}".format(ret_val))
        
        self.canSocket_from.setsockopt(socket.SOL_CAN_RAW, 
                                     socket.CAN_RAW_ERR_FILTER,
                                     can_error_filter)
        ret_val = self.canSocket_from.getsockopt(socket.SOL_CAN_RAW, socket.CAN_RAW_ERR_FILTER)
        print("Socket Option for CAN_RAW_ERR_FILTER is set to {}".format(ret_val))
        
        self.interface_from = interface_from
        self.interface_to = interface_to
        try: 
            self.canSocket_to.bind((interface_to,))
            self.canSocket_from.bind((interface_from,))
        except OSError: 
            print("Could not bind to SocketCAN interfaces")
        #put the sockets in blocking mode.
        self.canSocket_to.settimeout(None)
        self.canSocket_from.settimeout(None)

    def run(self, display=False):
        while True:
            raw_bytes = self.canSocket_from.recv(16)
            try:
                self.canSocket_to.send(raw_bytes)

            except OSError: #Buffer overflow usually from lack of connection.
                if display:
                    print("error writing can.")
                else:
                    pass
            raw_bytes_from = self.canSocket_to.recv(16)
            rawID,DLC,candata = struct.unpack(canformat,raw_bytes_from)
            canID = rawID & 0x1FFFFFFF
            if (rawID & CAN_ERR_FLAG) == CAN_ERR_FLAG:
                print("Found Error Frame.")
                print("RawID: {:08X}, data: {}".format(rawID,candata))

                if canID == 1:
                    print("TX timeout")
                elif canID == 2:
                    print ("Lost arbitration")
                elif canID == 4:
                    print("Controller problems")
                elif canID == 8:
                    print("Protocol violations")
                elif canID == 16:
                    print("Transceiver status") 
                elif canID == 32:
                    print("No Acknkowlegement on transmission")
                elif canID == 64:
                    print("Bus off")
                elif canID == 128:
                    print("{:03X}: Bus error. {}".format(canID,candata))
                elif canID == 0x100:
                    print("Controller restarted")
            elif rawID & CAN_RTR_FLAG == CAN_RTR_FLAG:
                print("Received RTR frame.")
            else:
                #Normal data frame
                if display:   
                    canID = rawID & 0x1FFFFFFF
                    candata_string = " ".join(["{:02X}".format(b) for b in candata])
                    print("{:08X} {}".format(canID, candata_string))

if __name__ == '__main__':
    bridge = CanBridge('can0','can1',bitrate_from=250000,bitrate_to=250000)
    bridge.run()
'''
https://github.com/torvalds/linux/blob/master/include/uapi/linux/can/error.h
/*
 * linux/can/error.h
 *
 * Definitions of the CAN error frame to be filtered and passed to the user.
 *
 * Author: Oliver Hartkopp <oliver.hartkopp@volkswagen.de>
 * Copyright (c) 2002-2007 Volkswagen Group Electronic Research
 * All rights reserved.
 *
 */

#ifndef CAN_ERROR_H
#define CAN_ERROR_H

#define CAN_ERR_DLC 8 /* dlc for error frames */

/* error class (mask) in can_id */
#define CAN_ERR_TX_TIMEOUT   0x00000001U /* TX timeout (by netdevice driver) */
#define CAN_ERR_LOSTARB      0x00000002U /* lost arbitration    / data[0]    */
#define CAN_ERR_CRTL         0x00000004U /* controller problems / data[1]    */
#define CAN_ERR_PROT         0x00000008U /* protocol violations / data[2..3] */
#define CAN_ERR_TRX          0x00000010U /* transceiver status  / data[4]    */
#define CAN_ERR_ACK          0x00000020U /* received no ACK on transmission */
#define CAN_ERR_BUSOFF       0x00000040U /* bus off */
#define CAN_ERR_BUSERROR     0x00000080U /* bus error (may flood!) */
#define CAN_ERR_RESTARTED    0x00000100U /* controller restarted */

/* arbitration lost in bit ... / data[0] */
#define CAN_ERR_LOSTARB_UNSPEC   0x00 /* unspecified */
                      /* else bit number in bitstream */

/* error status of CAN-controller / data[1] */
#define CAN_ERR_CRTL_UNSPEC      0x00 /* unspecified */
#define CAN_ERR_CRTL_RX_OVERFLOW 0x01 /* RX buffer overflow */
#define CAN_ERR_CRTL_TX_OVERFLOW 0x02 /* TX buffer overflow */
#define CAN_ERR_CRTL_RX_WARNING  0x04 /* reached warning level for RX errors */
#define CAN_ERR_CRTL_TX_WARNING  0x08 /* reached warning level for TX errors */
#define CAN_ERR_CRTL_RX_PASSIVE  0x10 /* reached error passive status RX */
#define CAN_ERR_CRTL_TX_PASSIVE  0x20 /* reached error passive status TX */
                      /* (at least one error counter exceeds */
                      /* the protocol-defined level of 127)  */

/* error in CAN protocol (type) / data[2] */
#define CAN_ERR_PROT_UNSPEC      0x00 /* unspecified */
#define CAN_ERR_PROT_BIT         0x01 /* single bit error */
#define CAN_ERR_PROT_FORM        0x02 /* frame format error */
#define CAN_ERR_PROT_STUFF       0x04 /* bit stuffing error */
#define CAN_ERR_PROT_BIT0        0x08 /* unable to send dominant bit */
#define CAN_ERR_PROT_BIT1        0x10 /* unable to send recessive bit */
#define CAN_ERR_PROT_OVERLOAD    0x20 /* bus overload */
#define CAN_ERR_PROT_ACTIVE      0x40 /* active error announcement */
#define CAN_ERR_PROT_TX          0x80 /* error occurred on transmission */

/* error in CAN protocol (location) / data[3] */
#define CAN_ERR_PROT_LOC_UNSPEC  0x00 /* unspecified */
#define CAN_ERR_PROT_LOC_SOF     0x03 /* start of frame */
#define CAN_ERR_PROT_LOC_ID28_21 0x02 /* ID bits 28 - 21 (SFF: 10 - 3) */
#define CAN_ERR_PROT_LOC_ID20_18 0x06 /* ID bits 20 - 18 (SFF: 2 - 0 )*/
#define CAN_ERR_PROT_LOC_SRTR    0x04 /* substitute RTR (SFF: RTR) */
#define CAN_ERR_PROT_LOC_IDE     0x05 /* identifier extension */
#define CAN_ERR_PROT_LOC_ID17_13 0x07 /* ID bits 17-13 */
#define CAN_ERR_PROT_LOC_ID12_05 0x0F /* ID bits 12-5 */
#define CAN_ERR_PROT_LOC_ID04_00 0x0E /* ID bits 4-0 */
#define CAN_ERR_PROT_LOC_RTR     0x0C /* RTR */
#define CAN_ERR_PROT_LOC_RES1    0x0D /* reserved bit 1 */
#define CAN_ERR_PROT_LOC_RES0    0x09 /* reserved bit 0 */
#define CAN_ERR_PROT_LOC_DLC     0x0B /* data length code */
#define CAN_ERR_PROT_LOC_DATA    0x0A /* data section */
#define CAN_ERR_PROT_LOC_CRC_SEQ 0x08 /* CRC sequence */
#define CAN_ERR_PROT_LOC_CRC_DEL 0x18 /* CRC delimiter */
#define CAN_ERR_PROT_LOC_ACK     0x19 /* ACK slot */
#define CAN_ERR_PROT_LOC_ACK_DEL 0x1B /* ACK delimiter */
#define CAN_ERR_PROT_LOC_EOF     0x1A /* end of frame */
#define CAN_ERR_PROT_LOC_INTERM  0x12 /* intermission */

/* error status of CAN-transceiver / data[4] */
/*                                             CANH CANL */
#define CAN_ERR_TRX_UNSPEC             0x00 /* 0000 0000 */
#define CAN_ERR_TRX_CANH_NO_WIRE       0x04 /* 0000 0100 */
#define CAN_ERR_TRX_CANH_SHORT_TO_BAT  0x05 /* 0000 0101 */
#define CAN_ERR_TRX_CANH_SHORT_TO_VCC  0x06 /* 0000 0110 */
#define CAN_ERR_TRX_CANH_SHORT_TO_GND  0x07 /* 0000 0111 */
#define CAN_ERR_TRX_CANL_NO_WIRE       0x40 /* 0100 0000 */
#define CAN_ERR_TRX_CANL_SHORT_TO_BAT  0x50 /* 0101 0000 */
#define CAN_ERR_TRX_CANL_SHORT_TO_VCC  0x60 /* 0110 0000 */
#define CAN_ERR_TRX_CANL_SHORT_TO_GND  0x70 /* 0111 0000 */
#define CAN_ERR_TRX_CANL_SHORT_TO_CANH 0x80 /* 1000 0000 */

/* controller specific additional information / data[5..7] */

#endif /* CAN_ERROR_H */
'''

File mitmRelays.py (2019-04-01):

import Adafruit_BBIO.GPIO as GPIO

class MITM():
    def __init__(self):
        GPIO.setup("P8_38",GPIO.OUT)
        GPIO.setup("P8_39",GPIO.OUT)
        GPIO.setup("P8_40",GPIO.OUT)
        GPIO.setup("P8_37",GPIO.OUT)
        GPIO.setup("P8_45",GPIO.OUT)
        GPIO.setup("P8_42",GPIO.OUT)
        GPIO.setup("P8_46",GPIO.OUT)
    
    def LED(self,state):
        if state:
            GPIO.output("P8_38",GPIO.HIGH)
        else:
            GPIO.output("P8_38",GPIO.LOW)
    
    def switch_1(self,state):
        if state:
            GPIO.output("P8_39",GPIO.HIGH)
        else:
            GPIO.output("P8_39",GPIO.LOW)
    
    def switch_2(self,state):
        if state:
            GPIO.output("P8_40",GPIO.HIGH)
        else:
            GPIO.output("P8_40",GPIO.LOW)
    
    def switch_3(self,state):
        if state:
            GPIO.output("P8_37",GPIO.HIGH)
        else:
            GPIO.output("P8_37",GPIO.LOW)
    
    def switch_4(self,state):
        if state:
            GPIO.output("P8_42",GPIO.HIGH)
        else:
            GPIO.output("P8_42",GPIO.LOW)
    
    def switch_5(self,state):
        if state:
            GPIO.output("P8_45",GPIO.HIGH)
        else:
            GPIO.output("P8_45",GPIO.LOW)
    
    def switch_6(self,state):
        if state:
            GPIO.output("P8_46",GPIO.HIGH)
        else:
            GPIO.output("P8_46",GPIO.LOW)

    def passthrough_all_with_resistors(self):
        """
        Terminating resistors are introduced.
        """
        self.switch_1(True) #Connect J1939
        self.switch_2(False) #Connect CAN2
        self.switch_3(False) #DCAN1 reads J1939
        self.switch_4(False) #Connect J1708
        self.switch_5(True) #DCAN0 reads CAN2
        self.switch_6(False) #Terminating Resitors connected

    def passthrough_all_monitor_j1939(self):
        """
        No Terminating resistors are introduced.
        """
        self.switch_1(False) #Disconnect J1939
        self.switch_2(False) #Connect CAN2
        self.switch_3(False) #DCAN1 reads J1939
        self.switch_4(False) #Connect J1708
        self.switch_5(False) #DCAN0 reads J1939
        self.switch_6(True) #DCAN0 connects to DCAN1
    
    def passthrough_all_monitor_can2(self):
        """
        No Terminating resistors are introduced.
        """
        self.switch_1(True) #connect J1939
        self.switch_2(True) #disconnect CAN2
        self.switch_3(True) #DCAN1 reads CAN2
        self.switch_4(False) #Connect J1708
        self.switch_5(True) #DCAN0 reads CAN2
        self.switch_6(True) #DCAN0 connects to DCAN1

    def mitm_can2(self):
        """
        Terminating resistors are introduced.
        """
        self.switch_1(True) #connect J1939
        self.switch_2(True) #disconnect CAN2
        self.switch_3(True) #DCAN1 reads CAN2A
        self.switch_4(False) #Connect J1708
        self.switch_5(True) #DCAN0 reads CAN2B
        self.switch_6(False) #Adds terminating resistors

    def mitm_J1939(self):
        """
        Terminating resistors are introduced.
        """
        self.switch_1(False) #disconnect J1939
        self.switch_2(False) #connect CAN2
        self.switch_3(False) #DCAN1 reads J1939A
        self.switch_4(False) #Connect J1708
        self.switch_5(False) #DCAN0 reads J1939B
        self.switch_6(False) #Adds terminating resistors
    


if __name__ == '__main__':
    import time
    mitm = MITM()
    mitm.LED(False)
    time.sleep(1)
    mitm.LED(True)

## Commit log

2019-02-24 Fixes after first build of MITM R03
    Contains schematics and instructions for board reworking.
    [DigiKey Order for MITM Rev 3 58341237.xlsx]
2019-03-04 Refactored the docs section and expanded readme. Added License
    [DigiKey Order for MITM Rev 3 58341237.xlsx, TruckCape BeagleBone Headers v4 - MITM.SchDoc, TruckCape J1708 and Relays v4 - MITM.SchDoc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]
2019-03-04 Added Errata for Rev 3
    Also included descriptions of the MITM standalone board and make hardware directories
    [Man-In-The-Middle Cable.PrjPcb, ManInTheMiddle for Hammond Male Pins 1455J.PcbDoc, ManInTheMiddleCable.SchDoc]
2019-03-04 Update readme with build instructions for the rev3
    Also added the gerber files for Rev 4 with a bill of materials.
2019-03-04 Compressed the bill of materials tables for MITM3
2019-03-04 Fixed Bill of materials tables
2019-03-05 Added details on controlling relays
2019-03-14 Added MITM example relay configuration
    Added some common examples of how to configure relays with Python and the AdaFruit_BBIO library.
2019-04-01 Documented Fixed for Rev 3 crossed wires
    [bridgeCAN.py]
